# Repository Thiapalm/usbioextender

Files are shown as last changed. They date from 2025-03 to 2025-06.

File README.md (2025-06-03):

# USB to IO Extender Board

<p align=center>
 
 
</p>

This is a hobby development board conceived for usage in my home lab. The board can be used as USB to serial adapter with no need to install any driver on the PC. It can be used as USB to I2C adapter and also USB to GPIO port extender. For the two later options, some code development may be necessary.  

The board has 4 extra GPIO ports that can be used as LED indicators (if the back jumpers are soldered). The board power is provided by the USB connector, and it can be used in 5V or 3V3 modes for serial, I2C and GPIO pins. 

## License and certification

This is an open source hardware project licensed under CERN-OHL-P. More details on [LICENSE.md](./LICENSE.md).  

This project is certified by OSHW: [Certification BR000019](https://certification.oshwa.org/br000019.html)

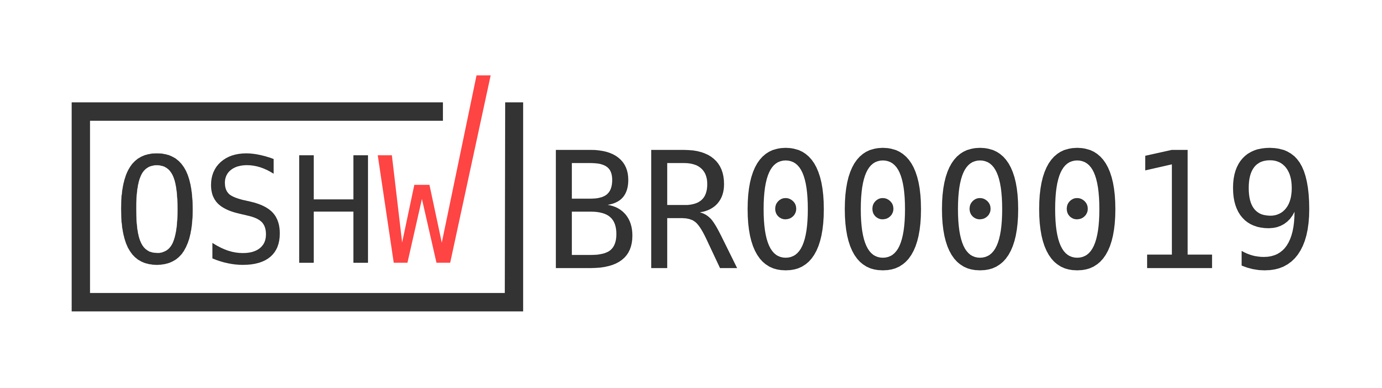
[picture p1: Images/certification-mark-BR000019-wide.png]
BR000019


## Project

The PCB project was developed in Kicad 9, all necessary project files are available in this repository and can be used freely, according to License.

## Board specifications

The board is based on the [**MCP2221**](https://www.microchip.com/en-us/product/MCP2221), and [**MCP23017**](https://www.microchip.com/en-us/product/MCP23017) from Microchip.  
Board features commonly used in Embedded Systems:
- USB-C connector
- I²C serial communication
- UART serial communication
- LED indicators (UART-TX, UART-RX, I²C, USB-Config and board power ON) or 4 extra GPIOs
- 16 GPIOs (5V or 3V3)
- Board power selector (5V / 3V3)
- The GPIO pins are breadboard compatible

## Board View 

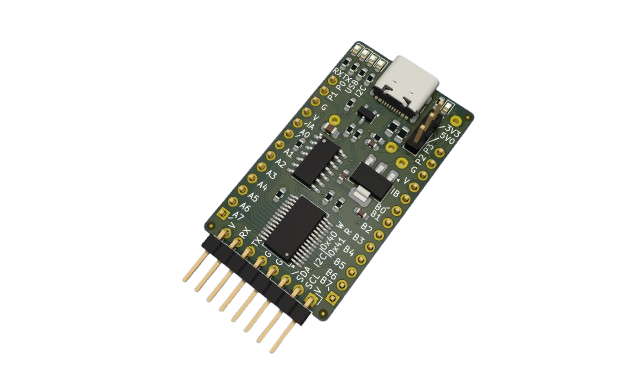
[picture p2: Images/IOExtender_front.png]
Front


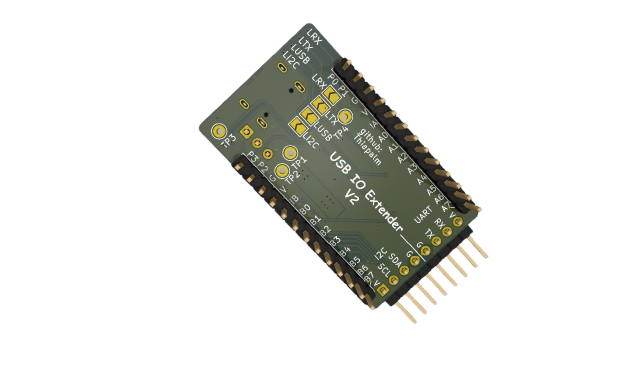
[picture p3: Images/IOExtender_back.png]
Back


## Version Revision

V1 - Not Published  
   - Added MCP23017 GPIOs on the header  
   - Added Jumper selector on LEDs  
   - Added Output voltage selection  
   - Added MCP2221 serial on Header  
   - Added MCP2221 I2C on Header   

V2 - Current Version
   - Changed USB connector to USB-C

## Firmware

There is no specific firmware for this board, but i have a driver developed in RUST for MCP23017 for use in embedded environments, see it in [crates.io](https://crates.io/crates/mcp23017-tp).

Also, you can use the IOExtender Control Center which is a software that can be used to control the I²C communication via Windows/Linux/Mac machines [iocc software](https://github.com/Thiapalm/iocc).

## Contribution

Unless you explicitly state otherwise, any contribution intentionally submitted for inclusion in the work by you, as defined in the CERN-OHL-P license, shall be licensed as above, without any additional terms or conditions.

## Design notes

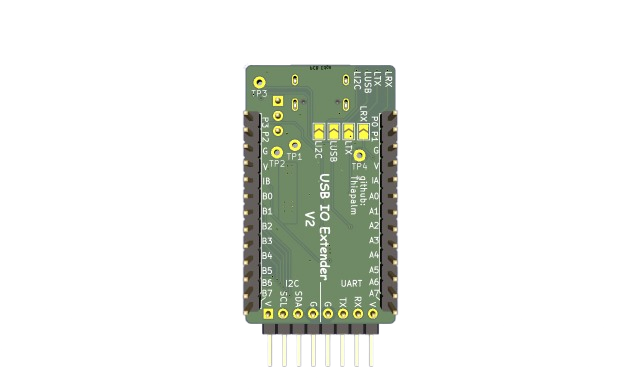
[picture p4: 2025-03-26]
Images/IOExtender_bottom.png

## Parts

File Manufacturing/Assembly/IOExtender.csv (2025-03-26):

Id | Designator | Footprint | Quantity | Designation | Supplier and ref
1 | U1 | SSOP-28_5.3x10.2mm_P0.65mm | 1 | MCP23017_SS
2 | R9,R3,R2,R10 | R_0603_1608Metric_Pad0.98x0.95mm_HandSolder | 4 | 10K
3 | R8,R7,R4,R5,R6 | R_0603_1608Metric_Pad0.98x0.95mm_HandSolder | 5 | 330
4 | R11,R1 | R_0603_1608Metric_Pad0.98x0.95mm_HandSolder | 2 | 33
5 | C2 | C_0603_1608Metric_Pad1.08x0.95mm_HandSolder | 1 | c=47e-7
6 | L1,L2 | R_0805_2012Metric_Pad1.20x1.40mm_HandSolder | 2 | 330R
7 | D6,D7 | LED_0603_1608Metric | 2 | Green
8 | D1,D5 | LED_0603_1608Metric | 2 | yellow
9 | C5 | USB_C_Receptacle_GCT_USB4105-xx-A_16P_TopMnt_Horizontal | 1 | USB4215-03-A
10 | J9 | PinHeader_1x08_P2.54mm_Horizontal | 1 | 22-28-8083
11 | J1 | PinHeader_1x03_P2.54mm_Vertical | 1 | 1x3 pin vertical
12 | D2 | LED_0603_1608Metric | 1 | Red
13 | U3 | SOT-223-3_TabPin2 | 1 | NCP1117IST33T3G
14 | U2 | SOIC-14_3.9x8.7mm_P1.27mm | 1 | MCP2221AxSL
15 | C6 | C_0603_1608Metric_Pad1.08x0.95mm_HandSolder | 1 | c=10e-6
16 | R12,R13 | R_0603_1608Metric_Pad0.98x0.95mm_HandSolder | 2 | 5.1K
17 | C8 | C_0805_2012Metric_Pad1.18x1.45mm_HandSolder | 1 | c=100e-9
18 | D4 | SOT-23-3 | 1 | CDSOT23-T05LC-Q
19 | C1 | C_0603_1608Metric_Pad1.08x0.95mm_HandSolder | 1 | c=470e-9
20 | J2,J5 | PinHeader_1x13_P2.54mm_Vertical | 2 | 1x13

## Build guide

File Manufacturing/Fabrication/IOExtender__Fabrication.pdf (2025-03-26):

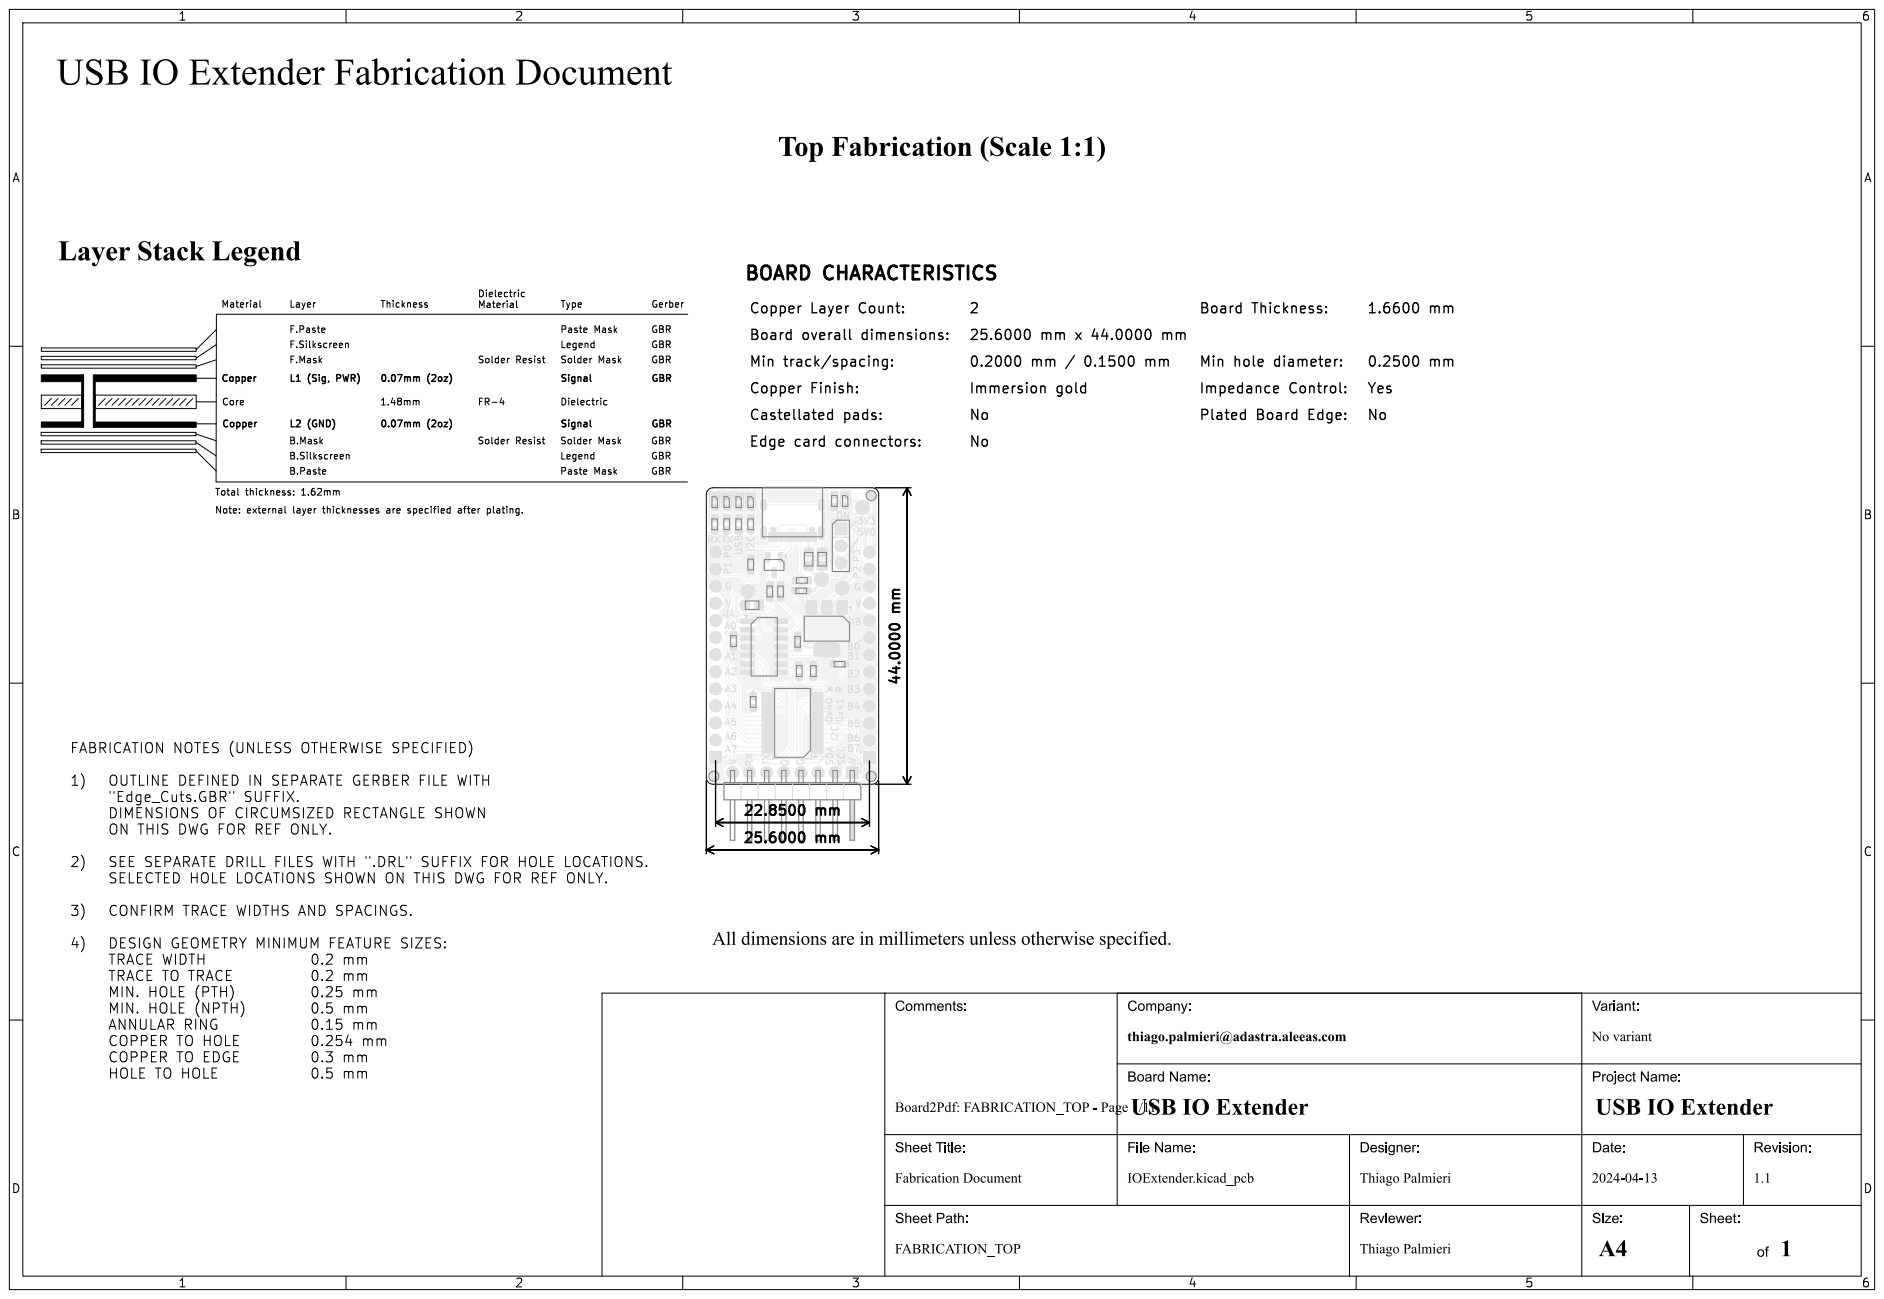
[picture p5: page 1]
USB G RX; SCL A6; SDA P¹; V Edge card; connectors: GBR GBR; Castellated; pads:; Total thickness:; Material; FR-4 Solder Resist; GBR; Legend; Copper; Layer Count:; No FABRICATION; NOTES (UNLESS OTHERWISE SPECIFIED); 1) OUTLINE; DEFINED IN; SEPARATE; GERBER; FILE; WITH; "Edge_Cuts.GBR"; SUFFIX. DIMENSIONS; OF CIRCUMSIZED; RECTANGLE SHOWN ON; THIS; DWG; FOR; REF ONLY. 2) SEE; DRILL; FILES; ".DRL"; SUFFIX; HOLE LOCATIONS. SELECTED; HOLE; LOCATIONS SHOWN ON; REF ONLY. 3) CONFIRM; TRACE; WIDTHS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

Sheet Path: FabricationDocument Comments: Board2Pdf:FABRICATION_TOP- Page1/11 USBIO ExtenderFabricationDocument

thiago.palmieri@adastra.aleeas.com

Revision: 1.1 Date: Project Name: 2024-04-13 Reviewer: ThiagoPalmieri Designer:

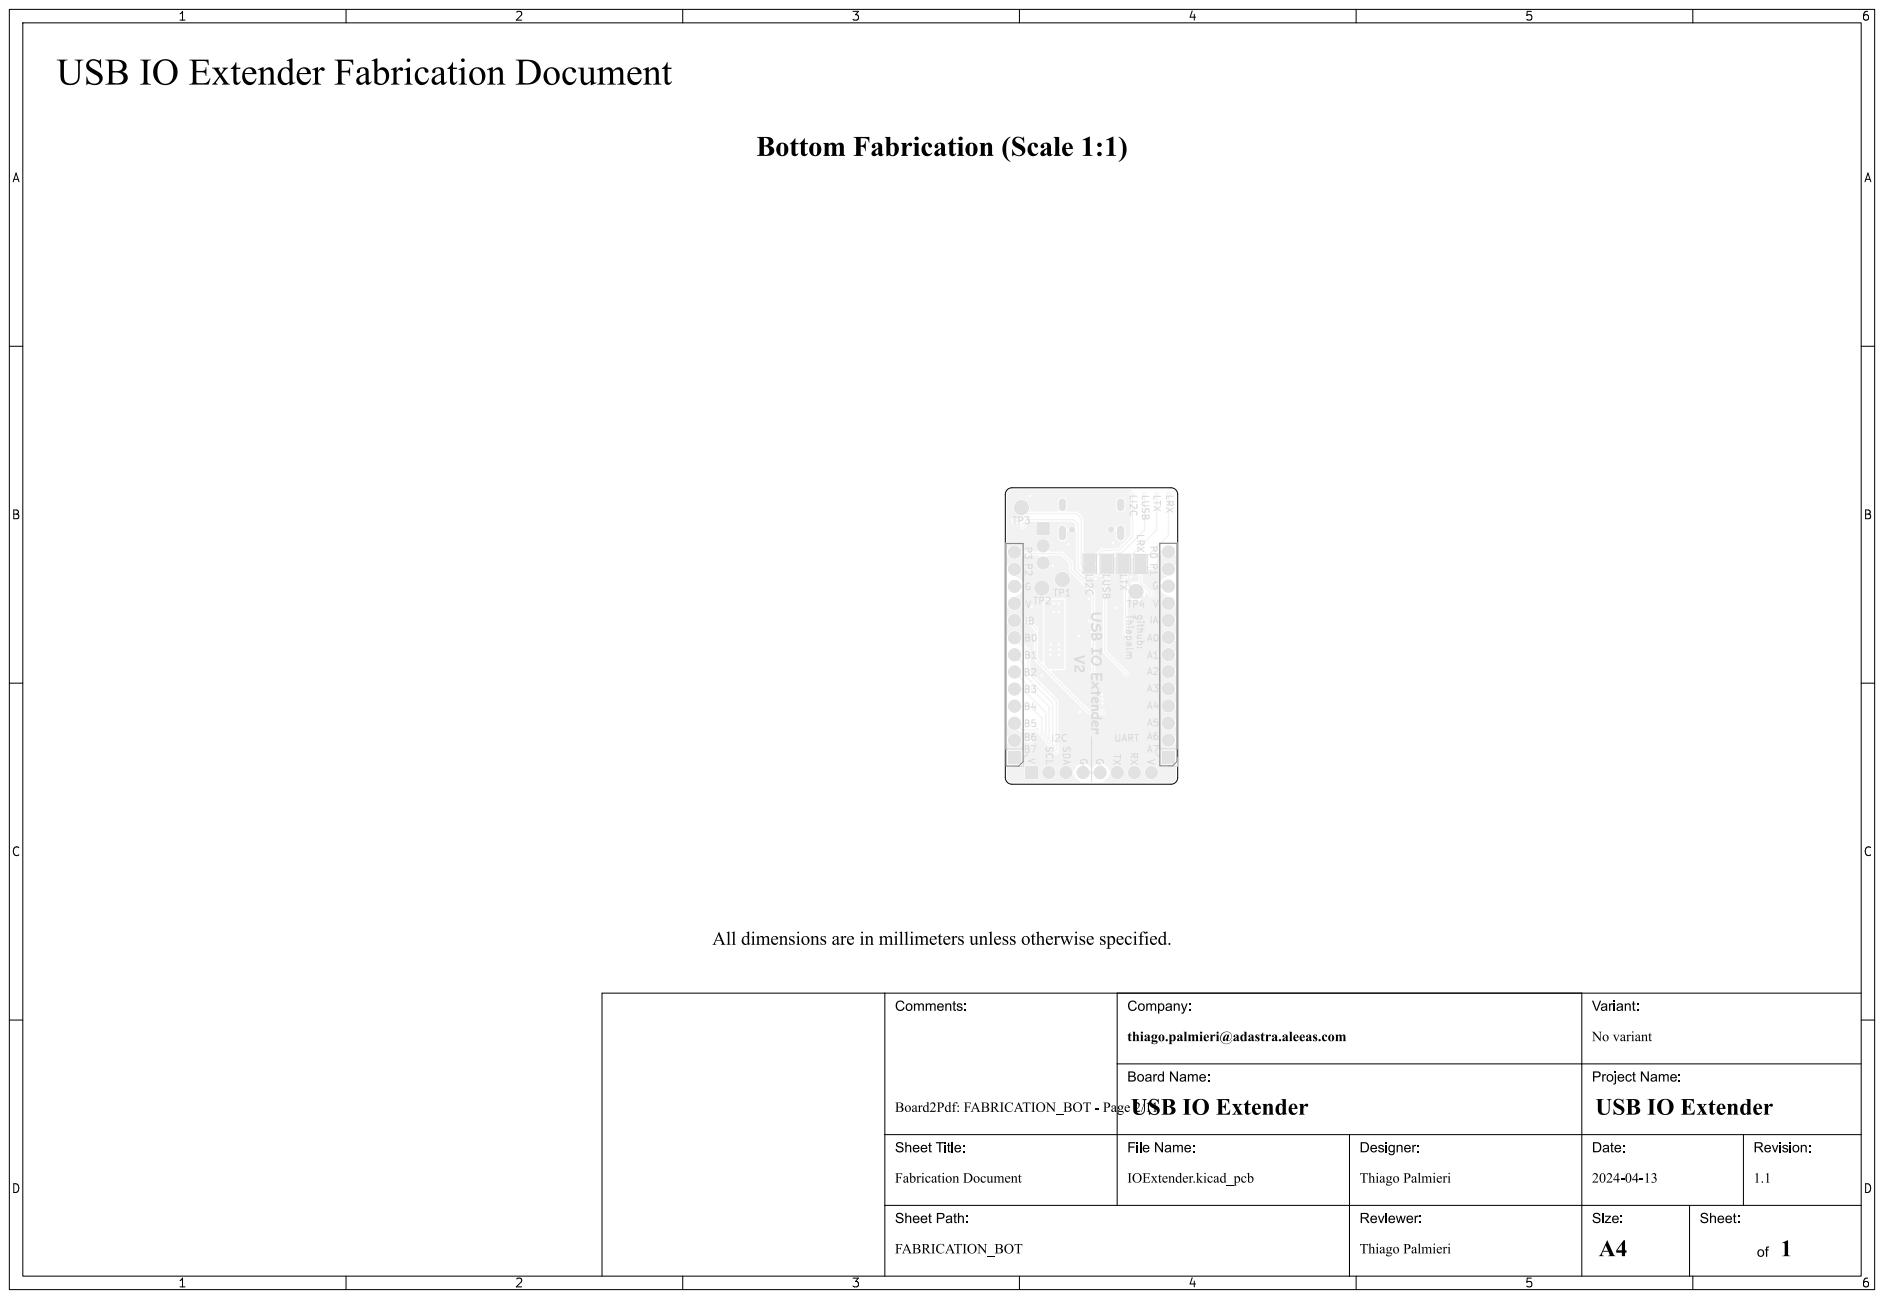
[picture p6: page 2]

thiago.palmieri@adastra.aleeas.com

Revision: 1.1 Date: Project Name: 2024-04-13 Reviewer: ThiagoPalmieri Designer:

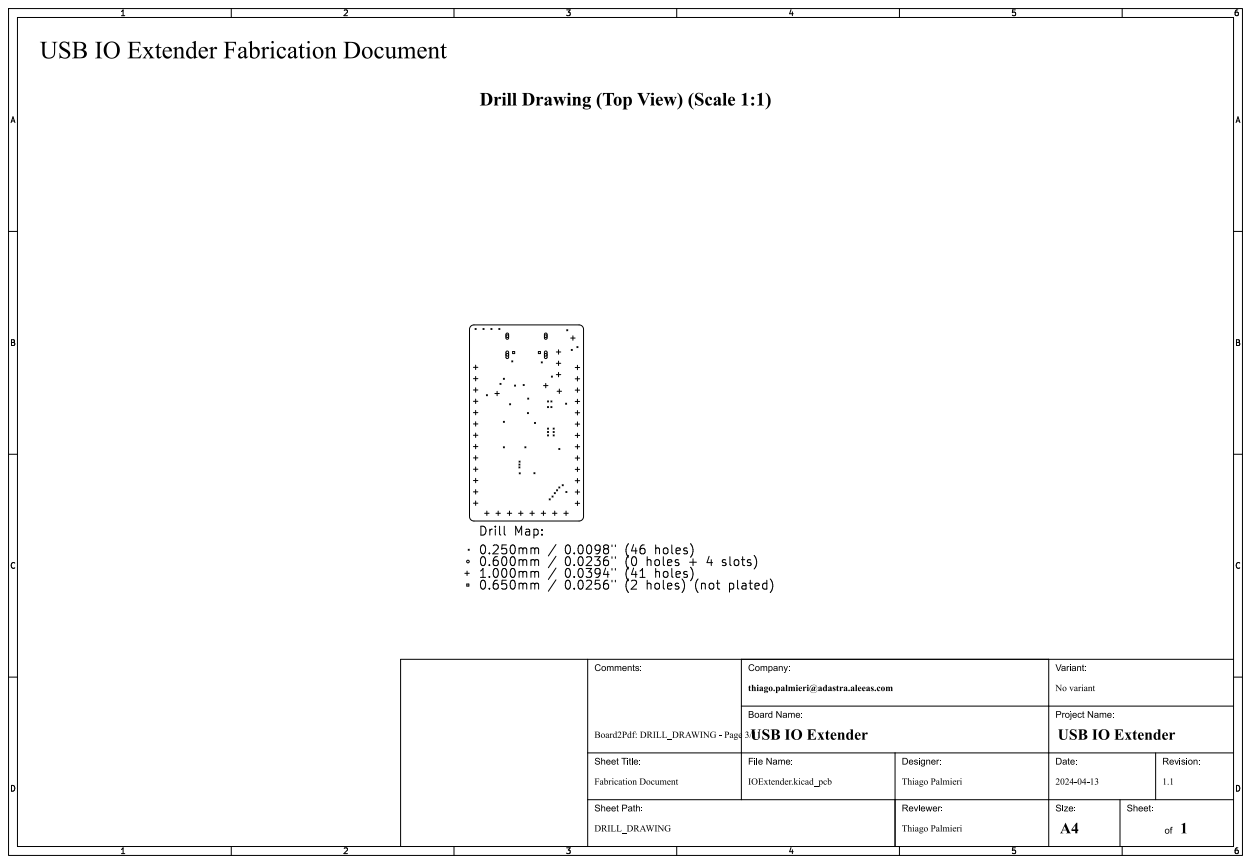
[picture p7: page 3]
D Sheet: of 1; Size: A4; IOExtender.kicad_pcb; ThiagoPalmieri Board Name:; Variant: No variant Company:; USBIO Extender; USBIO Extender Sheet Title:; File Name: DRILL_DRAWING

Sheet Path: FabricationDocument Comments: Board2Pdf:DRILL_DRAWING - Page3/11 USBIO ExtenderFabricationDocument

thiago.palmieri@adastra.aleeas.com

Revision: 1.1 Date: Project Name: 2024-04-13 Reviewer: ThiagoPalmieri Designer:

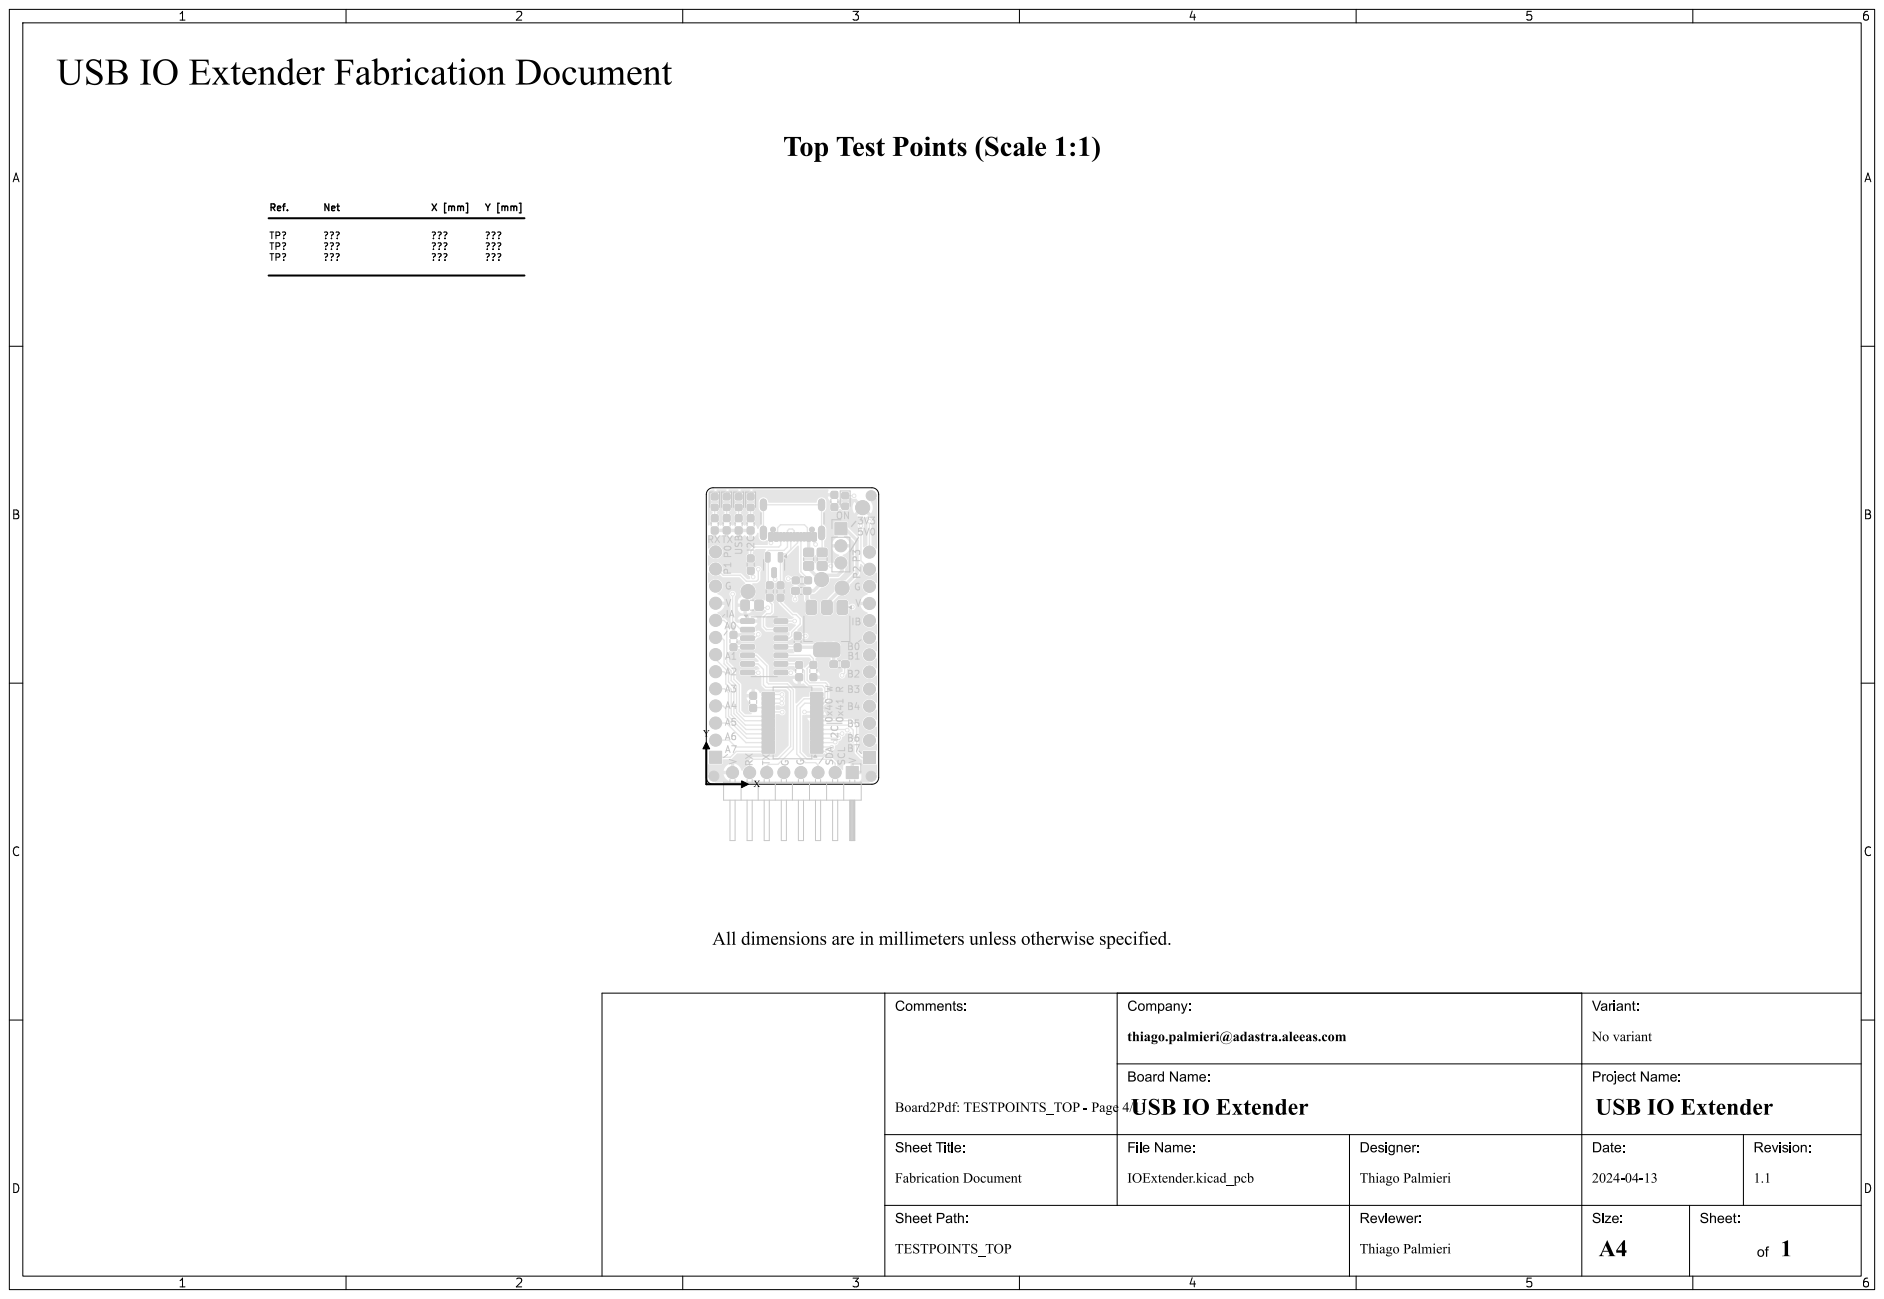
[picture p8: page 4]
USB G RX; SCL A6; SDA P¹; ??? Ref.; ??? Net; D Sheet: of 1; Size: A4; IOExtender.kicad_pcb; ThiagoPalmieri Board Name:; Variant: No variant Company:; USBIO Extender; USBIO Extender Sheet Title:; File Name: TESTPOINTS_TOP

Sheet Path: FabricationDocument Comments: Board2Pdf:TESTPOINTS_TOP- Page4/11 USBIO ExtenderFabricationDocument

thiago.palmieri@adastra.aleeas.com

Revision: 1.1 Date: Project Name: 2024-04-13 Reviewer: ThiagoPalmieri Designer:

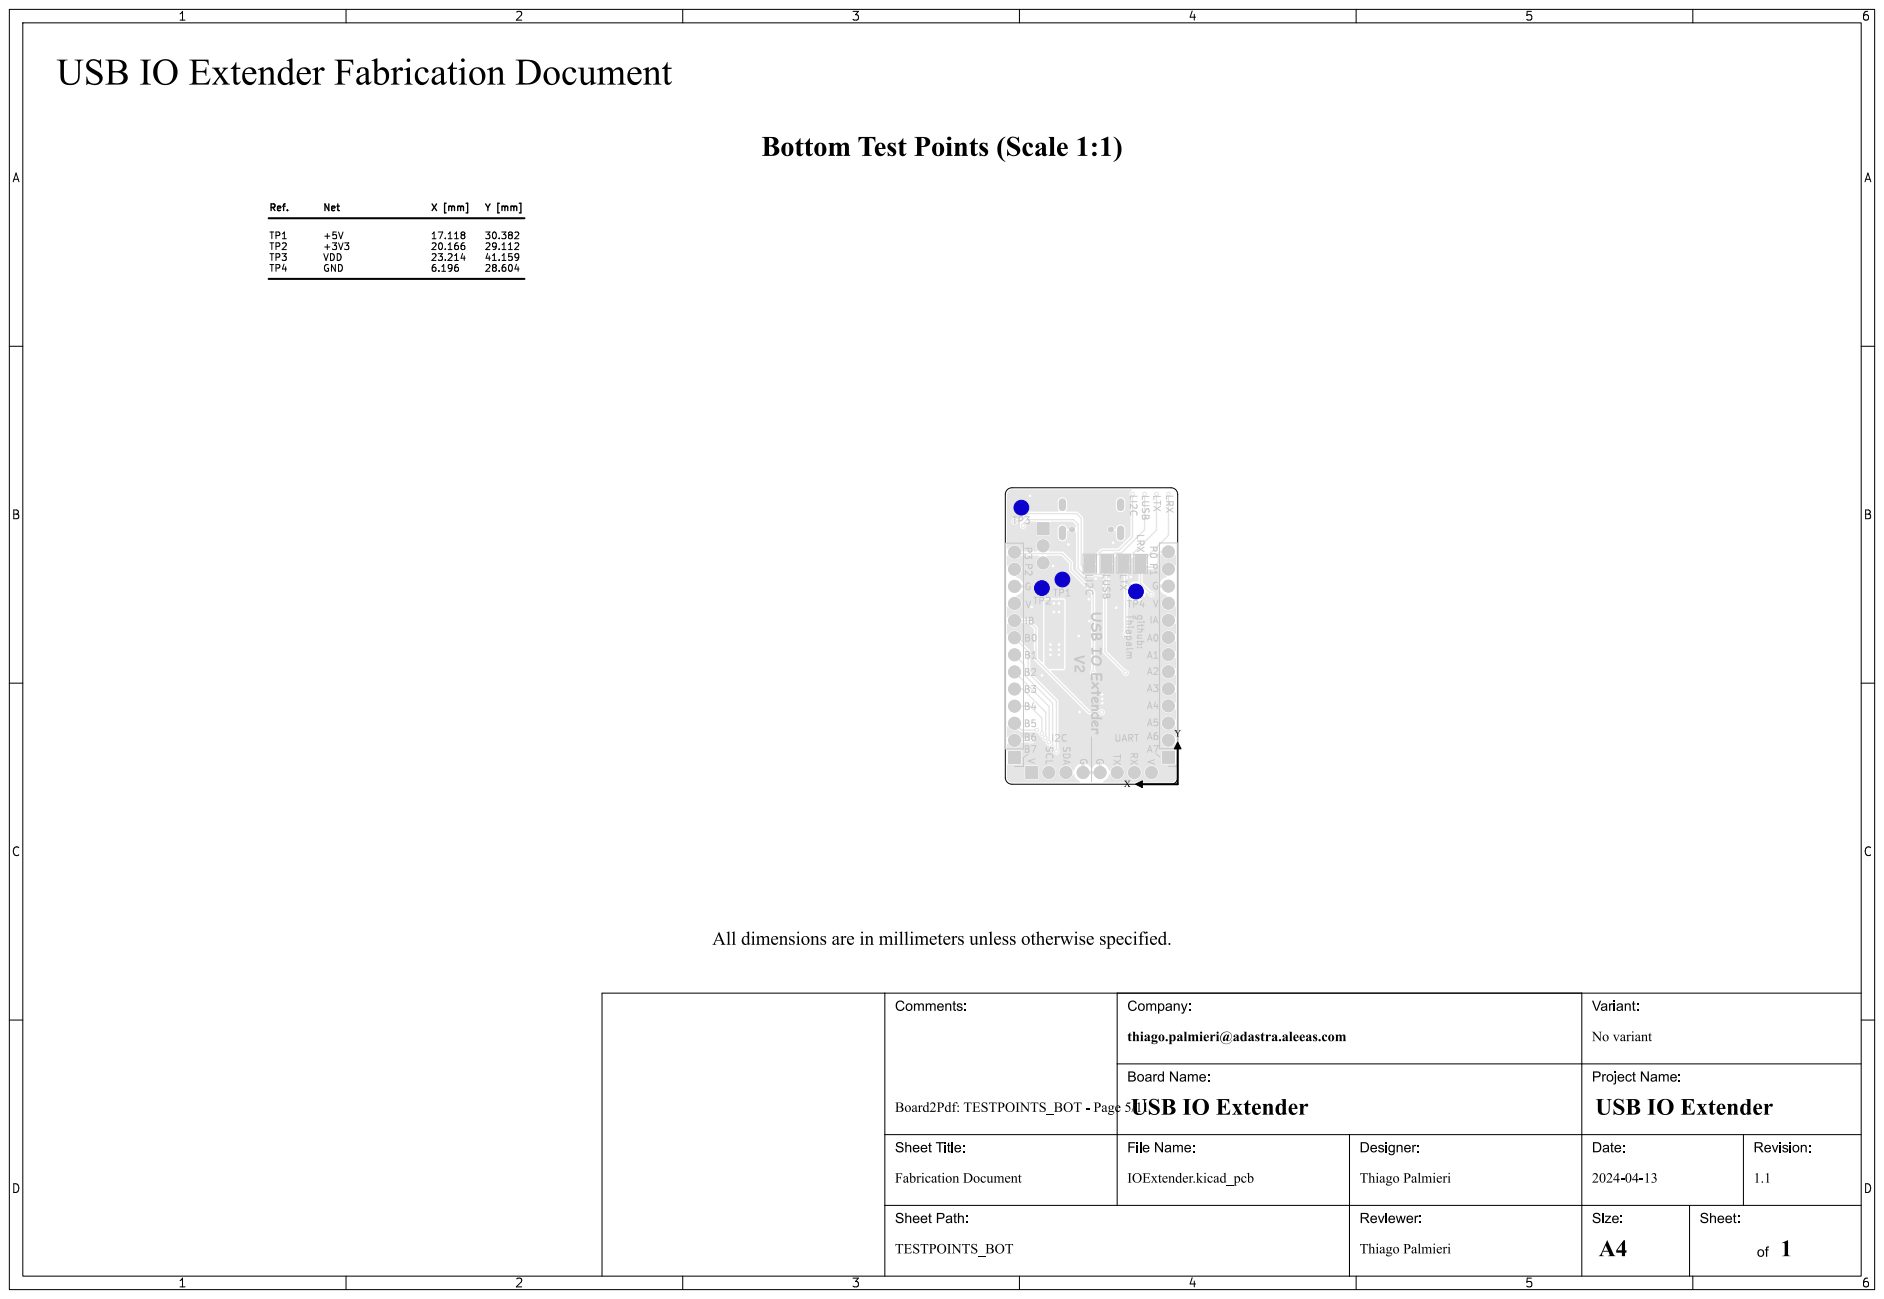
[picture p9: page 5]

thiago.palmieri@adastra.aleeas.com

Revision: 1.1 Date: Project Name: 2024-04-13 Reviewer: ThiagoPalmieri Designer:

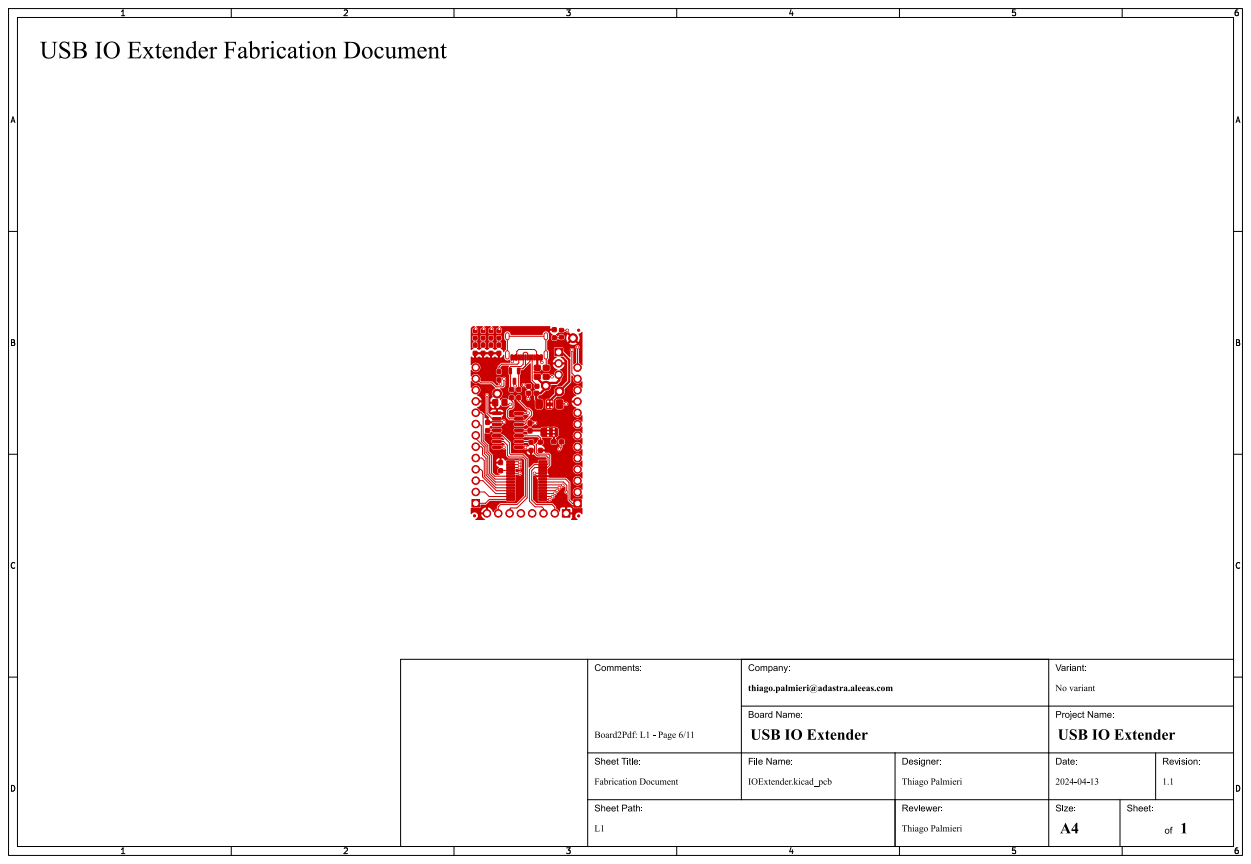
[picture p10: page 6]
D Sheet: of 1; Size: A4; IOExtender.kicad_pcb; ThiagoPalmieri Board Name:; Variant: No variant Company:; USBIO Extender; USBIO Extender Sheet Title:; File Name: L1Sheet Path: FabricationDocument Comments: Board2Pdf:L1 - Page6/11 USBIO ExtenderFabricationDocument

thiago.palmieri@adastra.aleeas.com

Revision: 1.1 Date: Project Name: 2024-04-13 Reviewer: ThiagoPalmieri Designer:

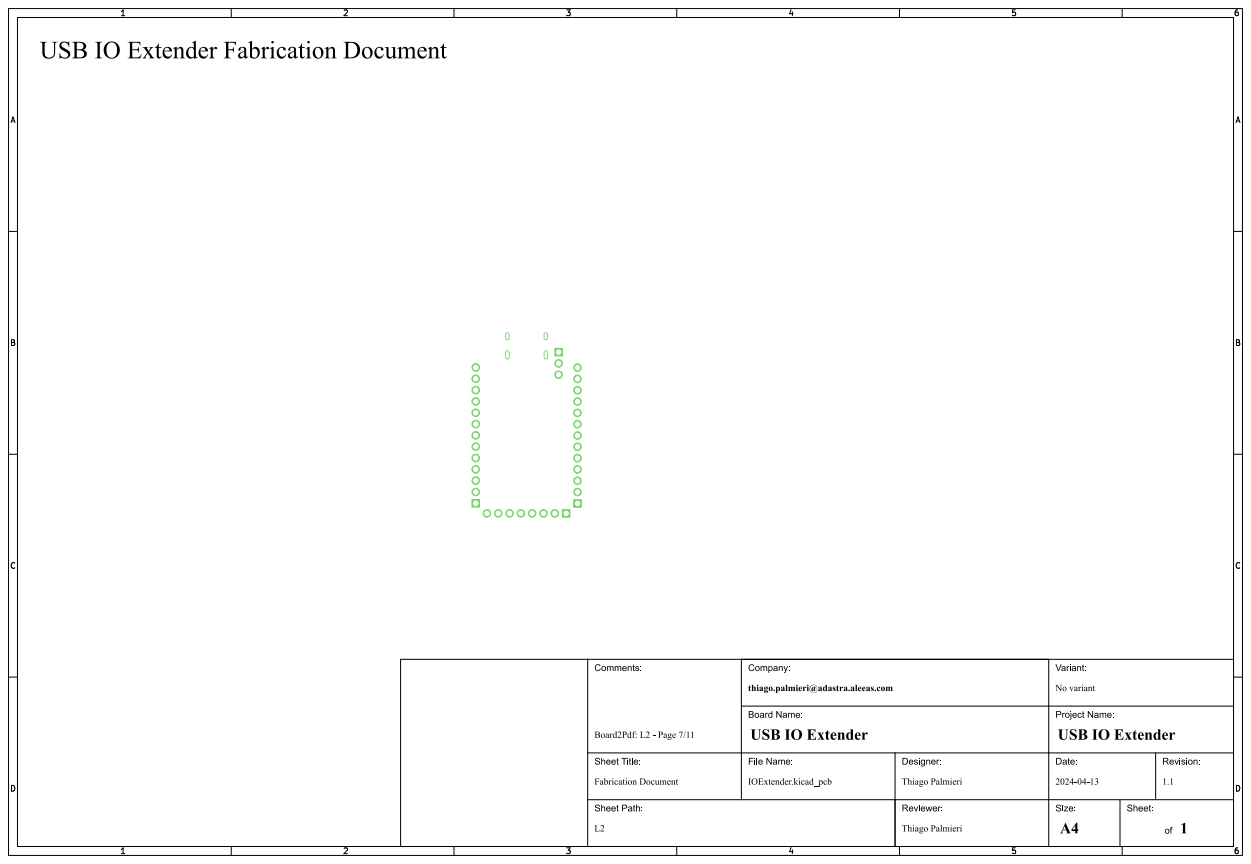
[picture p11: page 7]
D Sheet: of 1; Size: A4; IOExtender.kicad_pcb; ThiagoPalmieri Board Name:; Variant: No variant Company:; USBIO Extender; USBIO Extender Sheet Title:; File Name: L2Sheet Path: FabricationDocument Comments: Board2Pdf:L2 - Page7/11 USBIO ExtenderFabricationDocument

thiago.palmieri@adastra.aleeas.com

Revision: 1.1 Date: Project Name: 2024-04-13 Reviewer: ThiagoPalmieri Designer:

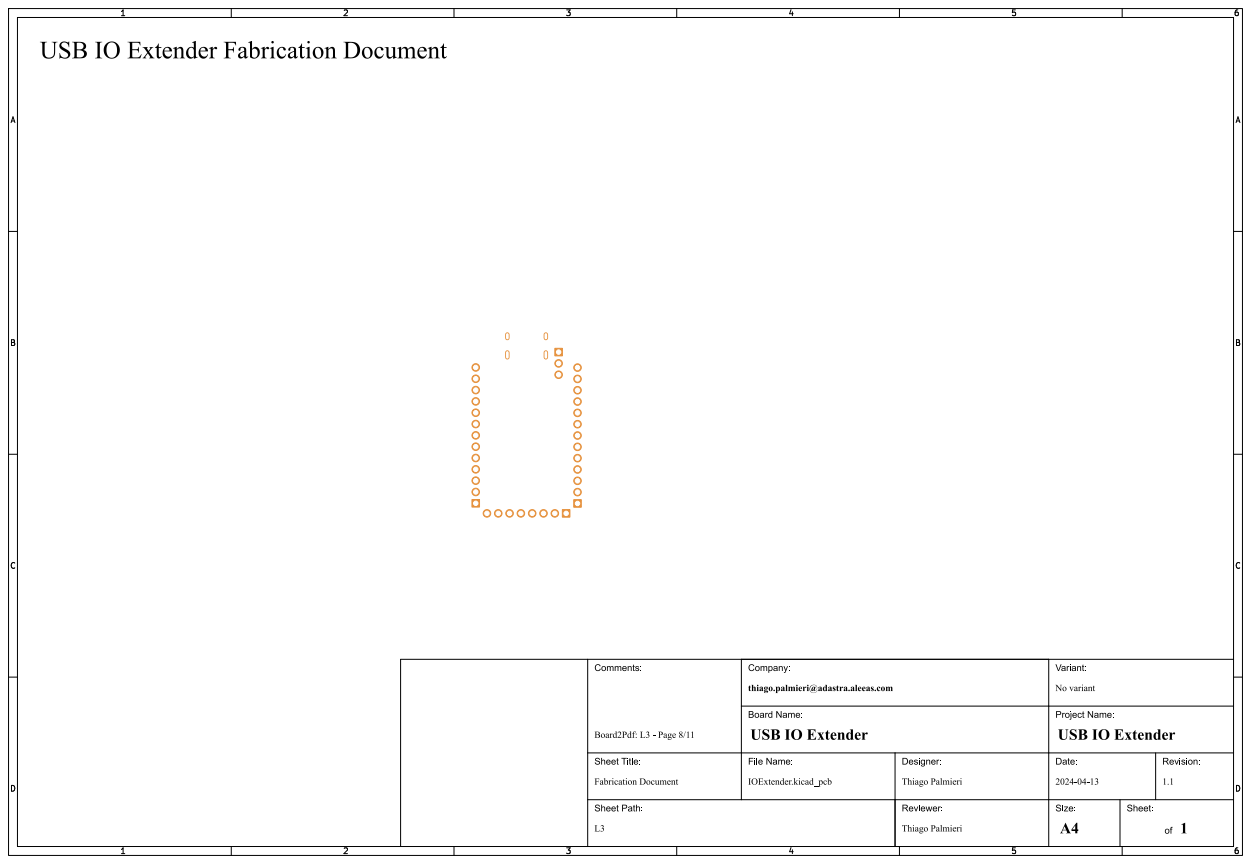
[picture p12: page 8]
D Sheet: of 1; Size: A4; IOExtender.kicad_pcb; ThiagoPalmieri Board Name:; Variant: No variant Company:; USBIO Extender; USBIO Extender Sheet Title:; File Name: L3Sheet Path: FabricationDocument Comments: Board2Pdf:L3 - Page8/11 USBIO ExtenderFabricationDocument

thiago.palmieri@adastra.aleeas.com

Revision: 1.1 Date: Project Name: 2024-04-13 Reviewer: ThiagoPalmieri Designer:

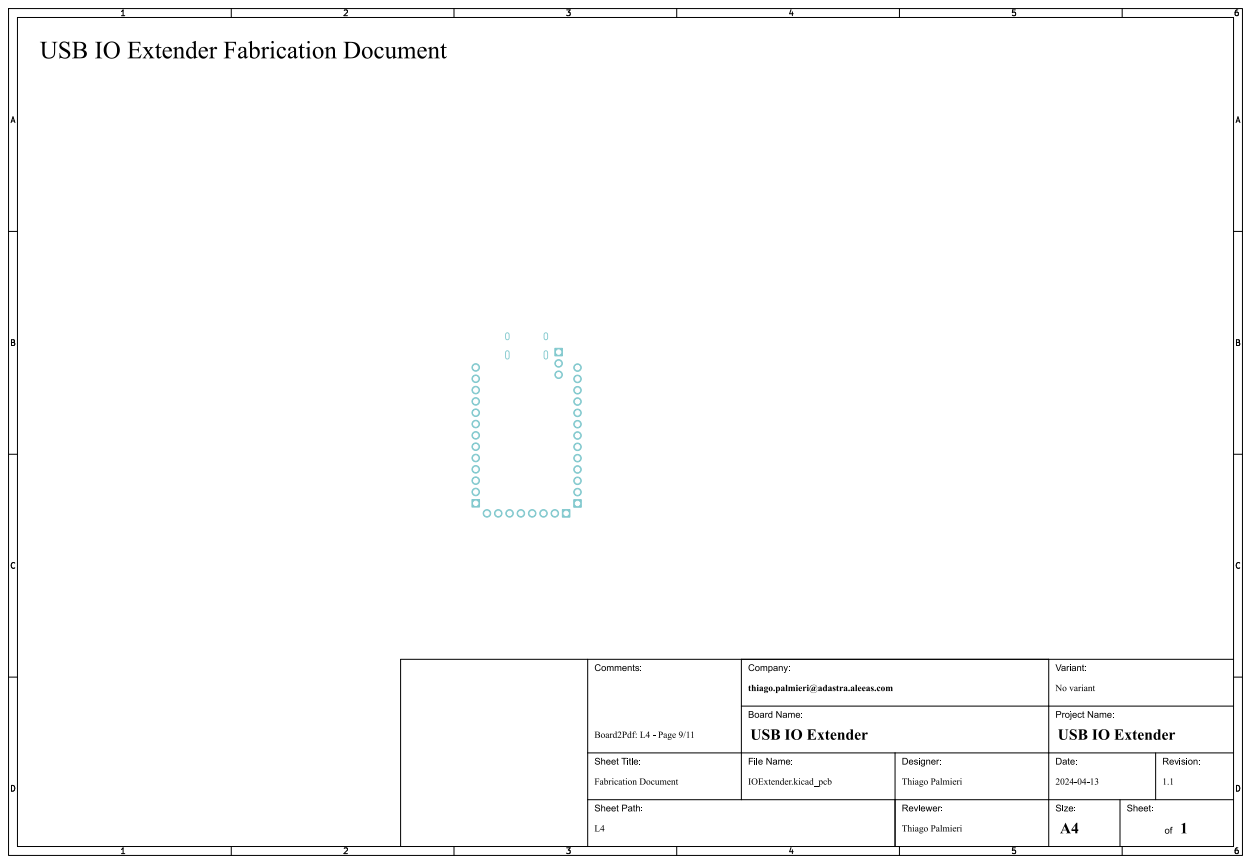
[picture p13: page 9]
D Sheet: of 1; Size: A4; IOExtender.kicad_pcb; ThiagoPalmieri Board Name:; Variant: No variant Company:; USBIO Extender; USBIO Extender Sheet Title:; File Name: L4Sheet Path: FabricationDocument Comments: Board2Pdf:L4 - Page9/11 USBIO ExtenderFabricationDocument

thiago.palmieri@adastra.aleeas.com

Revision: 1.1 Date: Project Name: 2024-04-13 Reviewer: ThiagoPalmieri Designer:

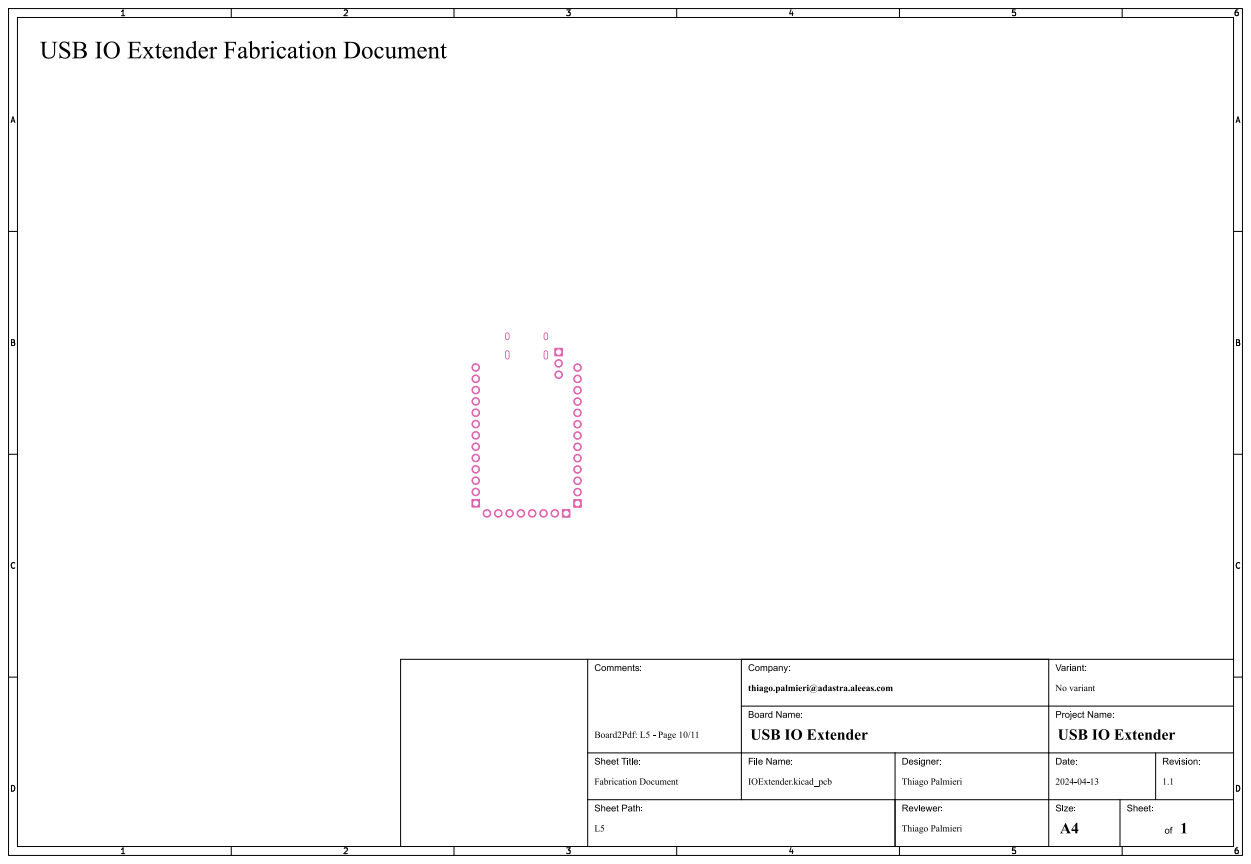
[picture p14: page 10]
D Sheet: of 1; Size: A4; IOExtender.kicad_pcb; ThiagoPalmieri Board Name:; Variant: No variant Company:; USBIO Extender; USBIO Extender Sheet Title:; File Name: L5Sheet Path: FabricationDocument Comments: Board2Pdf:L5 - Page10/11 USBIO ExtenderFabricationDocument

thiago.palmieri@adastra.aleeas.com

Revision: 1.1 Date: Project Name: 2024-04-13 Reviewer: ThiagoPalmieri Designer:

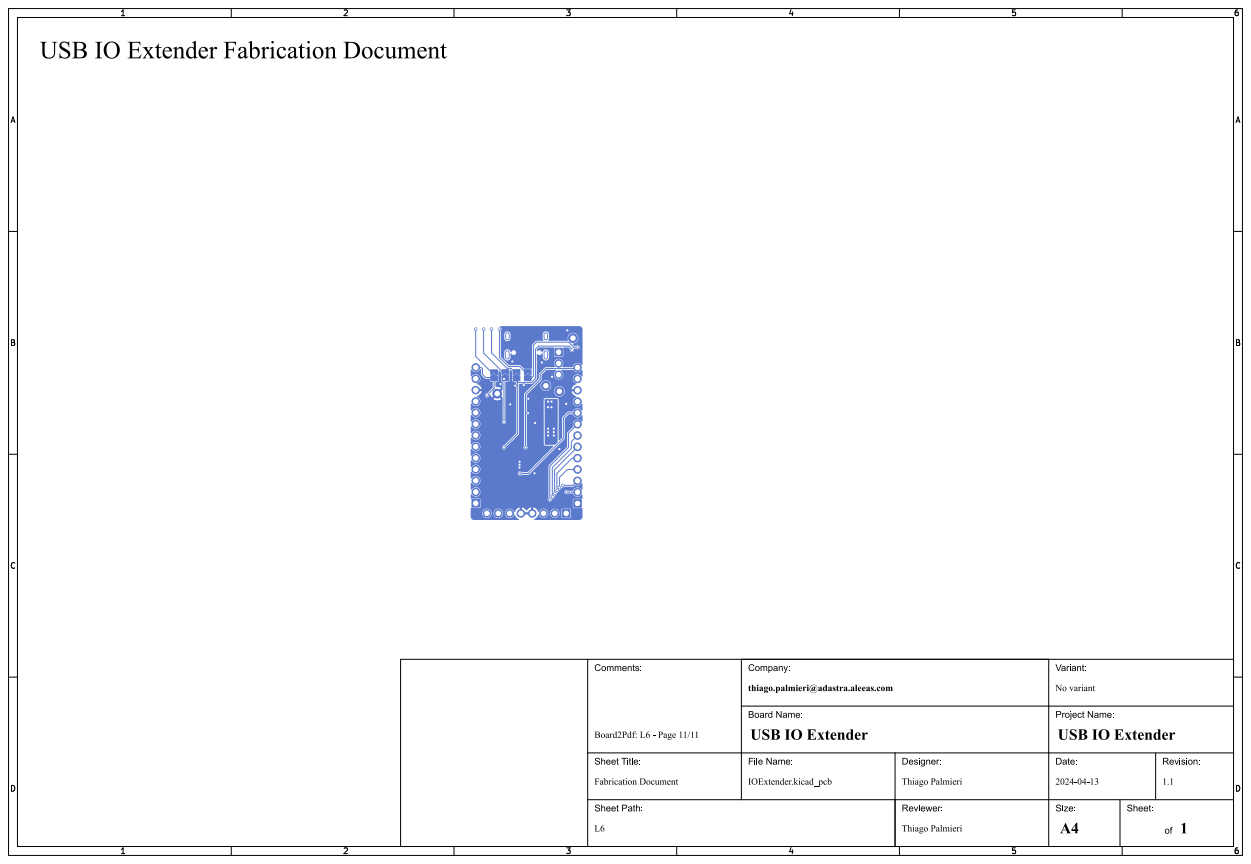
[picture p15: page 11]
D Sheet: of 1; Size: A4; IOExtender.kicad_pcb; ThiagoPalmieri Board Name:; Variant: No variant Company:; USBIO Extender; USBIO Extender Sheet Title:; File Name: L6Sheet Path: FabricationDocument Comments: Board2Pdf:L6 - Page11/11 USBIO ExtenderFabricationDocument

thiago.palmieri@adastra.aleeas.com

Revision: 1.1 Date: Project Name: 2024-04-13 Reviewer: ThiagoPalmieri Designer:

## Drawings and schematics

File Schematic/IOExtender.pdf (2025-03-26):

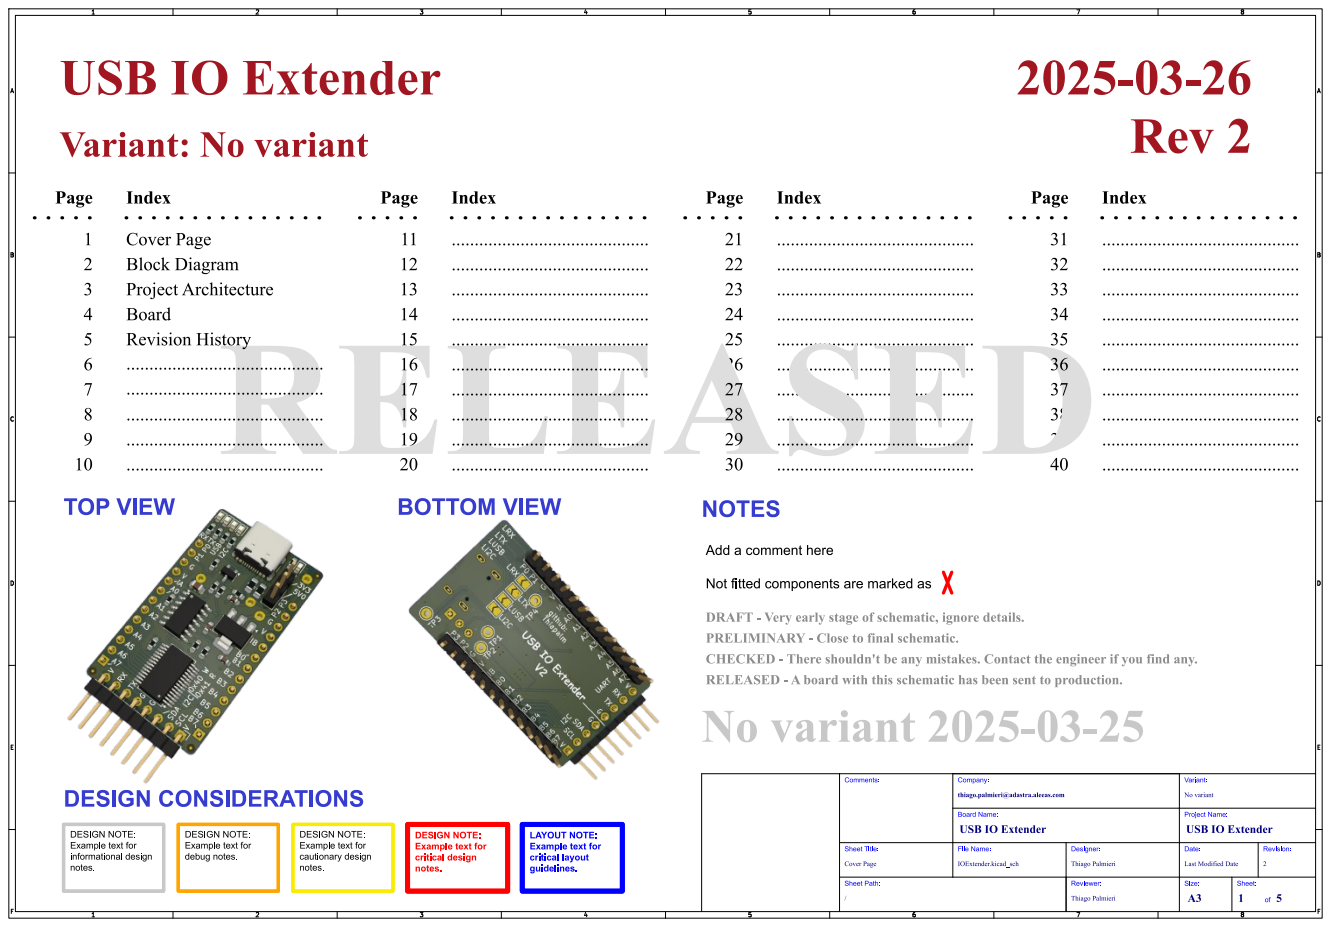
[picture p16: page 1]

........................................... DRAFT - Veryearlystageof schematic,ignoredetails.

........................................... Not fitted components are marked as

PRELIMINARY - Closetofinal schematic.
CHECKED - Thereshouldn'tbeanymistakes.Contacttheengineerif youfindany.
RELEASED - A boardwiththisschematichasbeensenttoproduction.
Novariant2025-03-25

thiago.palmieri@adastra.aleeas.com

Revision: 2 Date: Project Name: LastModified Date Reviewer: ThiagoPalmieri Designer:

File: Project Architecture.kicad_sch DESIGN NOTE:
Example text for
informational design
notes.

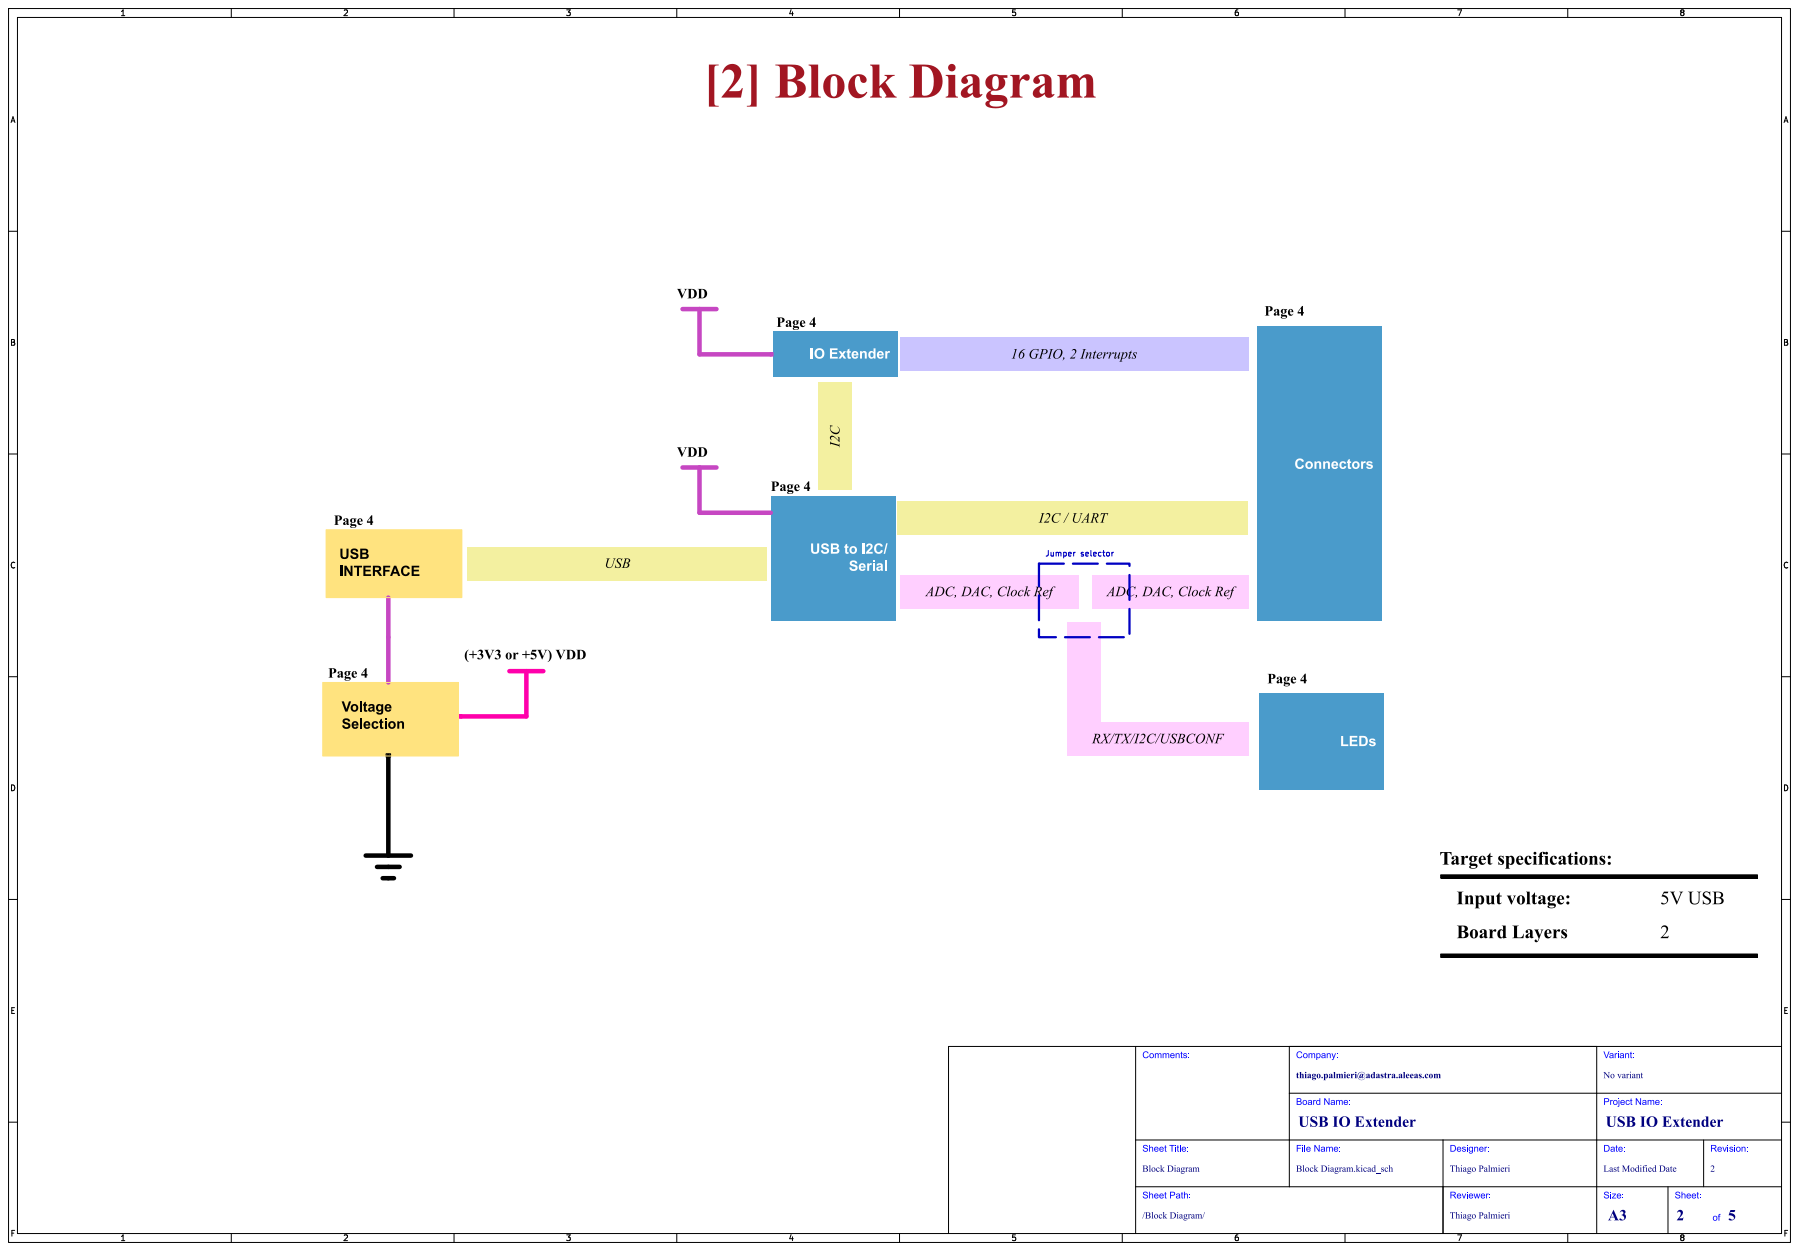
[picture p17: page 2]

Voltage

RX/TX/I2C/USBCONF

thiago.palmieri@adastra.aleeas.com

/Block Diagram/ Sheet Path: Block Diagram

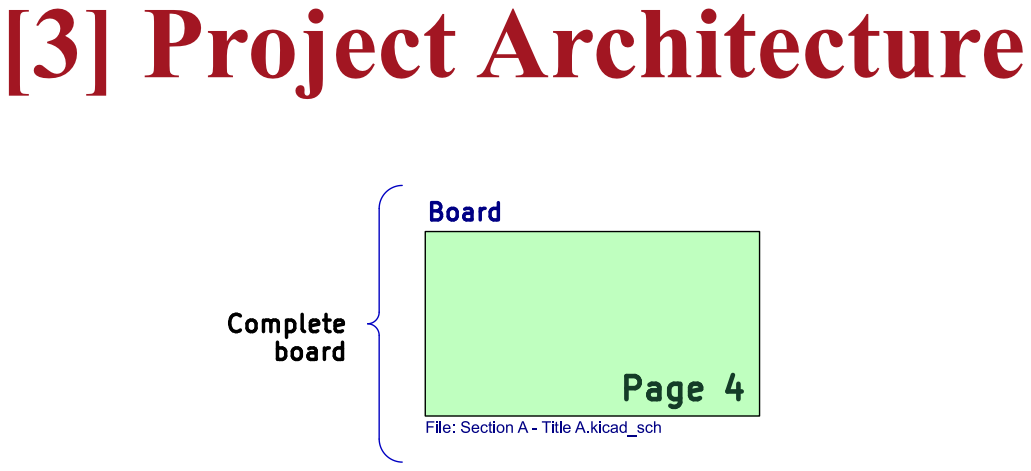
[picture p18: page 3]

File: Section A - Title A.kicad_sch [3] ProjectArchitecture

/ProjectArchitecture/ Sheet Path: ProjectArchitecture Comments:

thiago.palmieri@adastra.aleeas.com

Revision: 2 Date: Project Name: LastModified Date Reviewer: ThiagoPalmieri Designer:

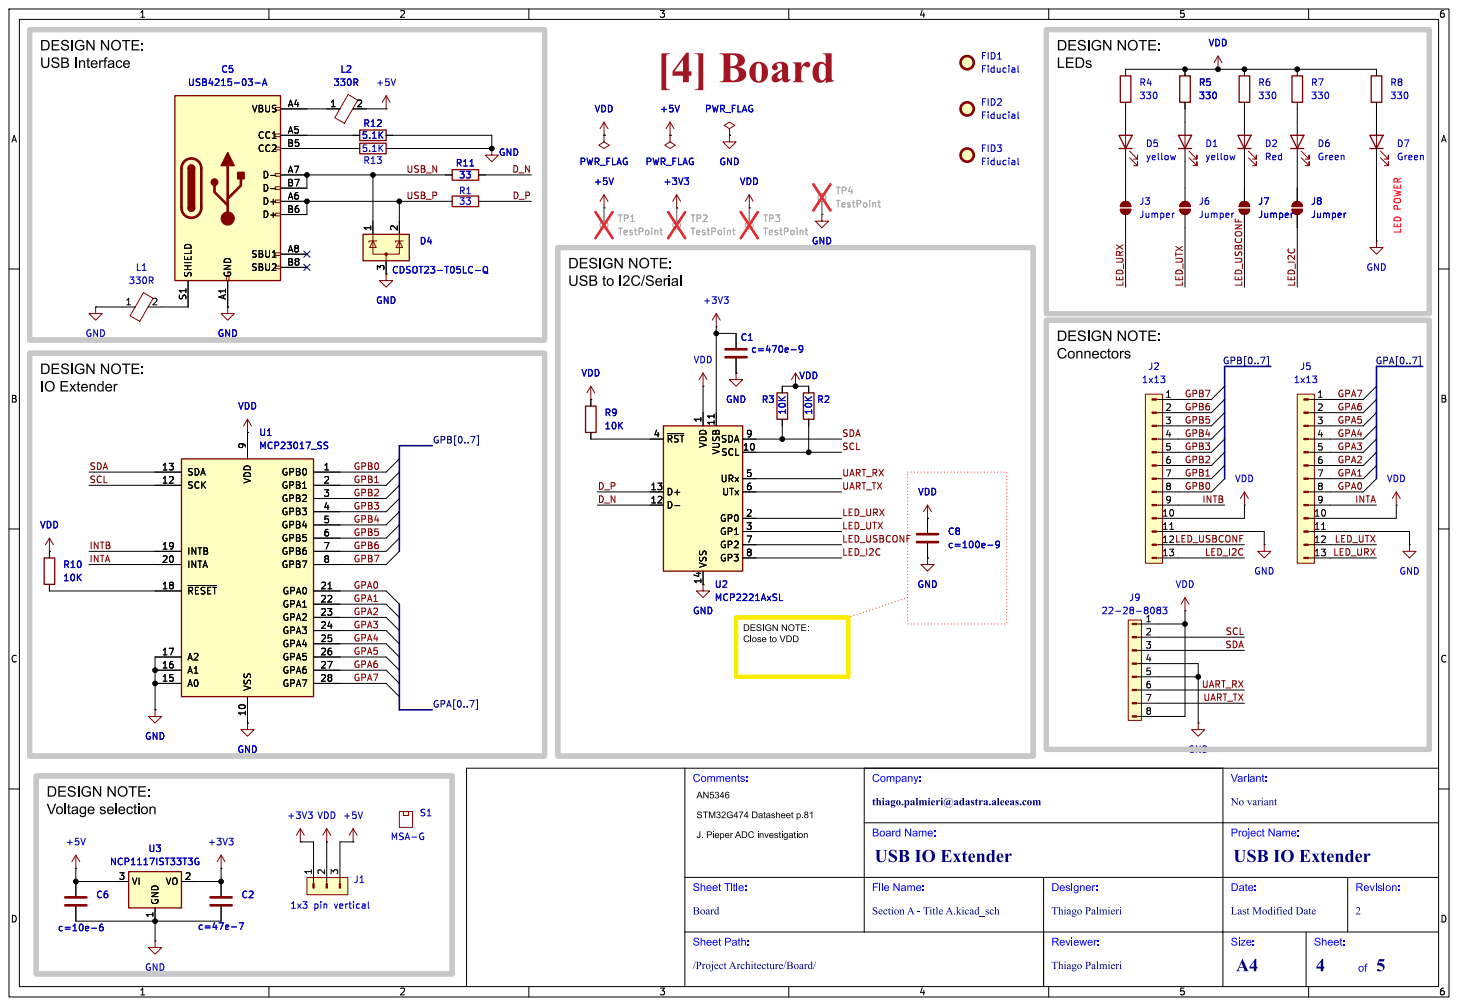
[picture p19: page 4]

1 VSS 14 VUSB 11 SDA 9 SCL 10 URx 5 UTx 6 GP0 2 GP1 3 GP2 7 GP3 8 GND GND GND

1 VSS 14 VUSB 11 SDA 9 SCL 10 URx 5 UTx 6 GP0 2 GP1 3 GP2 7 GP3 8 U2 MCP2221AxSL

thiago.palmieri@adastra.aleeas.com

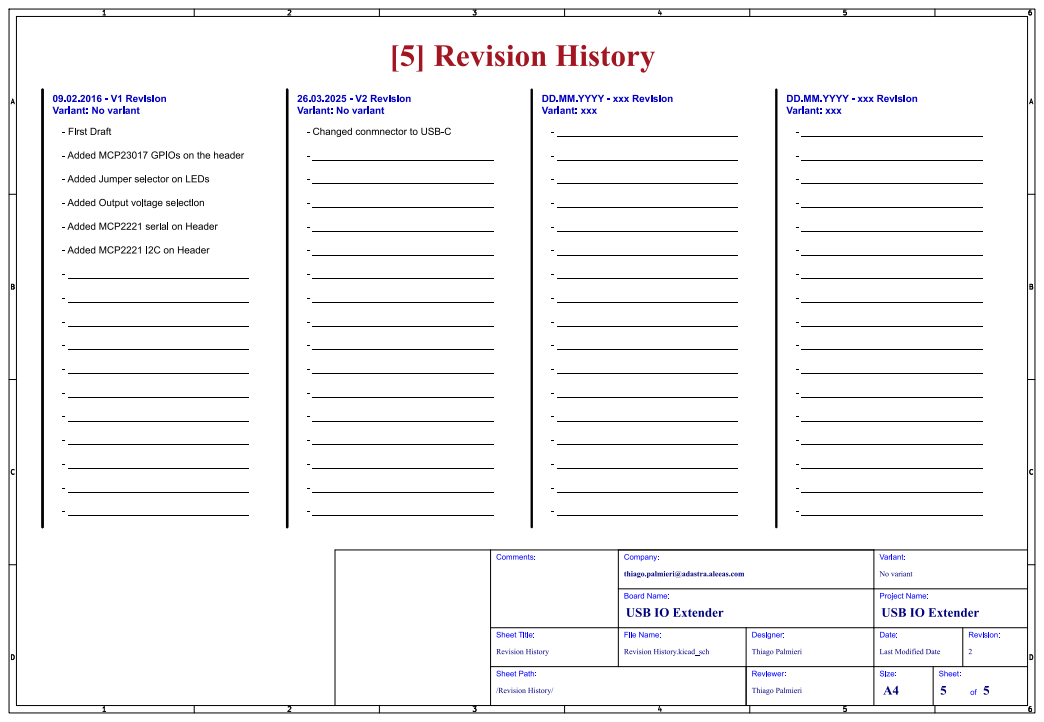
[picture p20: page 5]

09.02.2016 - V1 Revision
Variant: No variant
- First Draft - Added MCP23017 GPIOs on the header

26.03.2025 - V2 Revision
- Changed conmnector to USB-C

DD.MM.YYYY - xxx Revision
Variant: xxx

- Added Jumper selector on LEDs

- Added Output voltage selection

- Added MCP2221 serial on Header

/RevisionHistory/ Sheet Path: RevisionHistory Comments:

thiago.palmieri@adastra.aleeas.com

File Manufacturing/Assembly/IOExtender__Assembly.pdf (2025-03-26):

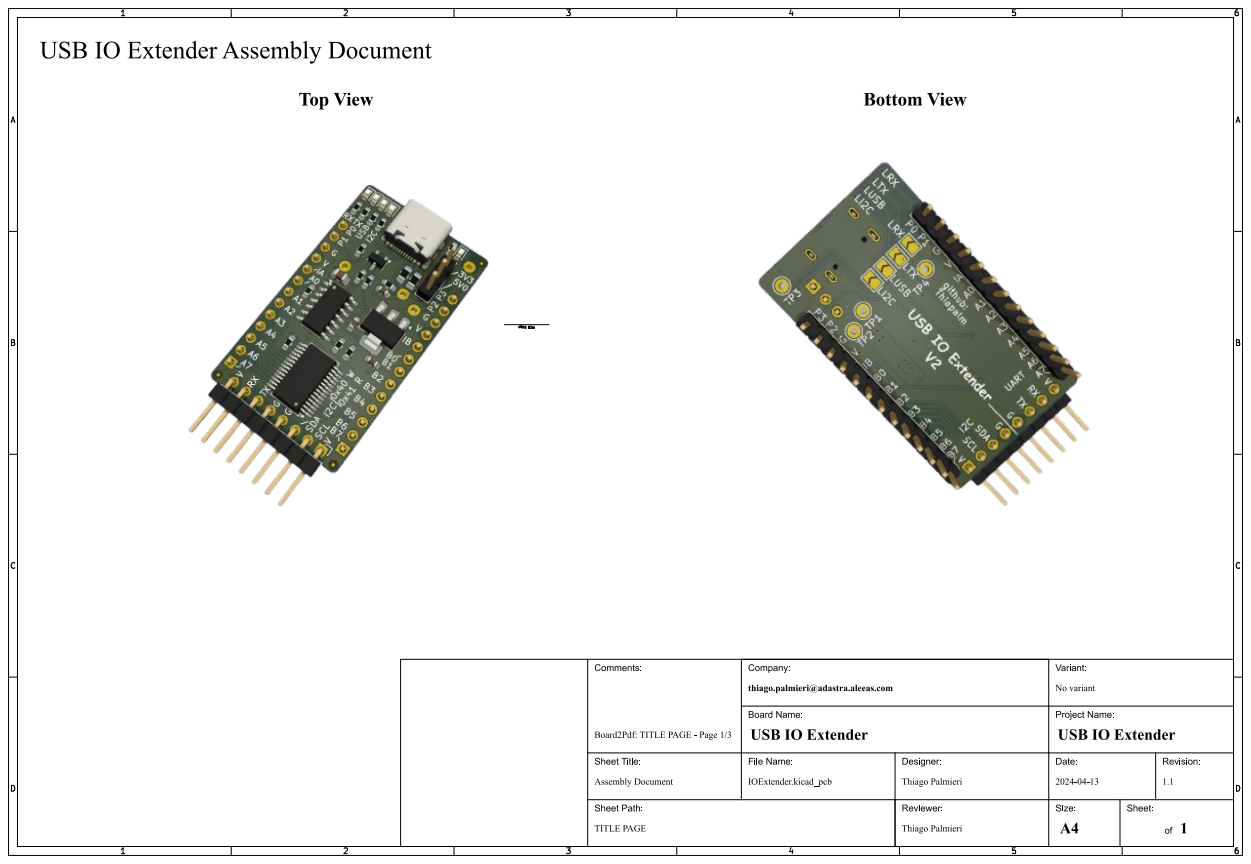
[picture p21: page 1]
D Sheet: of 1; Size: A4; IOExtender.kicad_pcb; ThiagoPalmieri Board Name:; Variant: No variant Company:; USBIO Extender; USBIO Extender Sheet Title:; File Name: TITLE PAGE

Sheet Path: AssemblyDocument Comments: Board2Pdf:TITLE PAGE- Page1/3 USBIO ExtenderAssemblyDocument

thiago.palmieri@adastra.aleeas.com

Revision: 1.1 Date: Project Name: 2024-04-13 Reviewer: ThiagoPalmieri Designer:

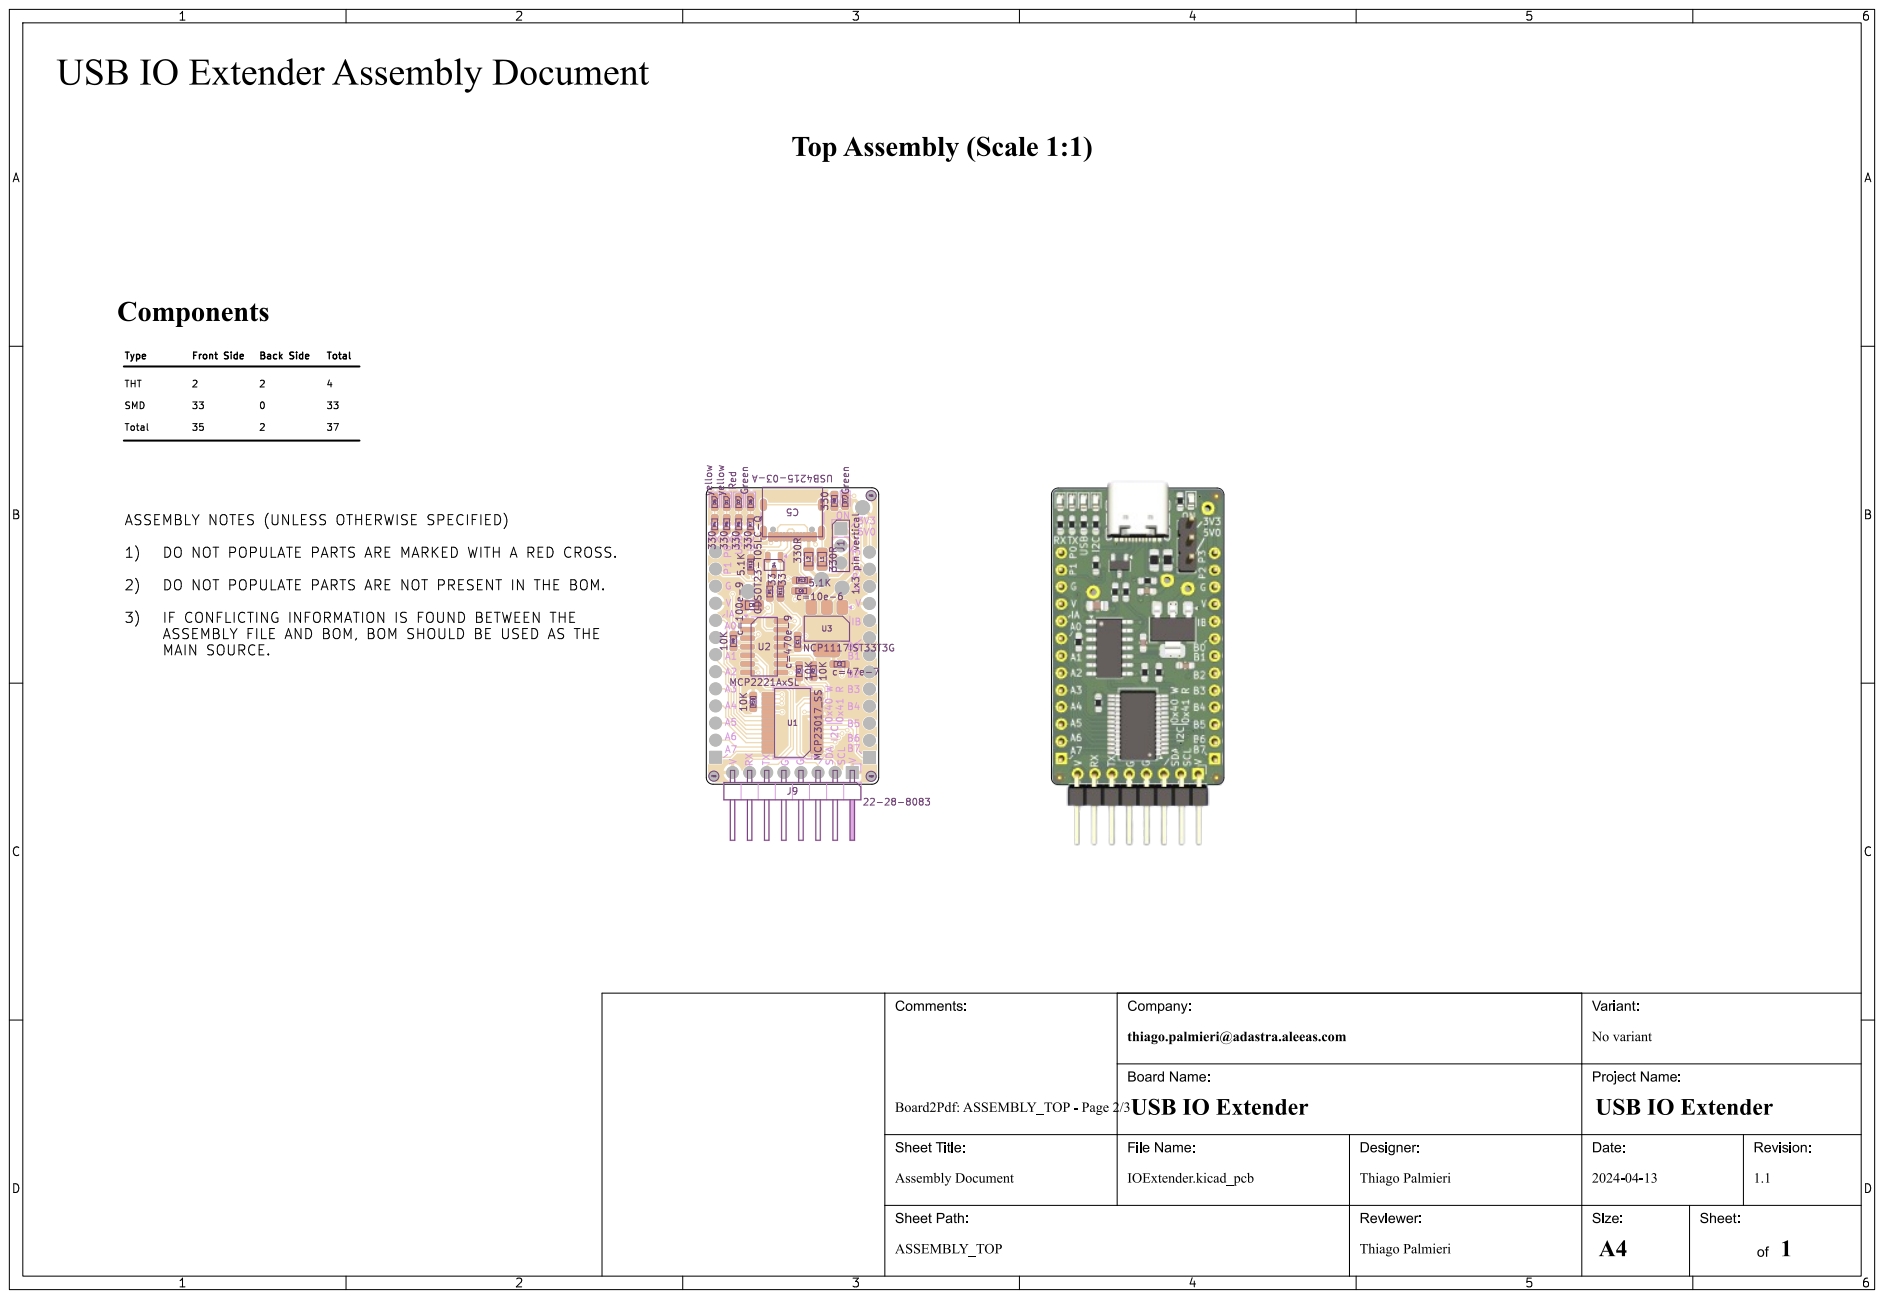
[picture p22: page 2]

Sheet Path: AssemblyDocument Comments: Board2Pdf:ASSEMBLY_TOP- Page2/3 USBIO ExtenderAssemblyDocument

37 ASSEMBLY NOTES (UNLESS OTHERWISE SPECIFIED)

thiago.palmieri@adastra.aleeas.com

Revision: 1.1 Date: Project Name: 2024-04-13 Reviewer: ThiagoPalmieri Designer:

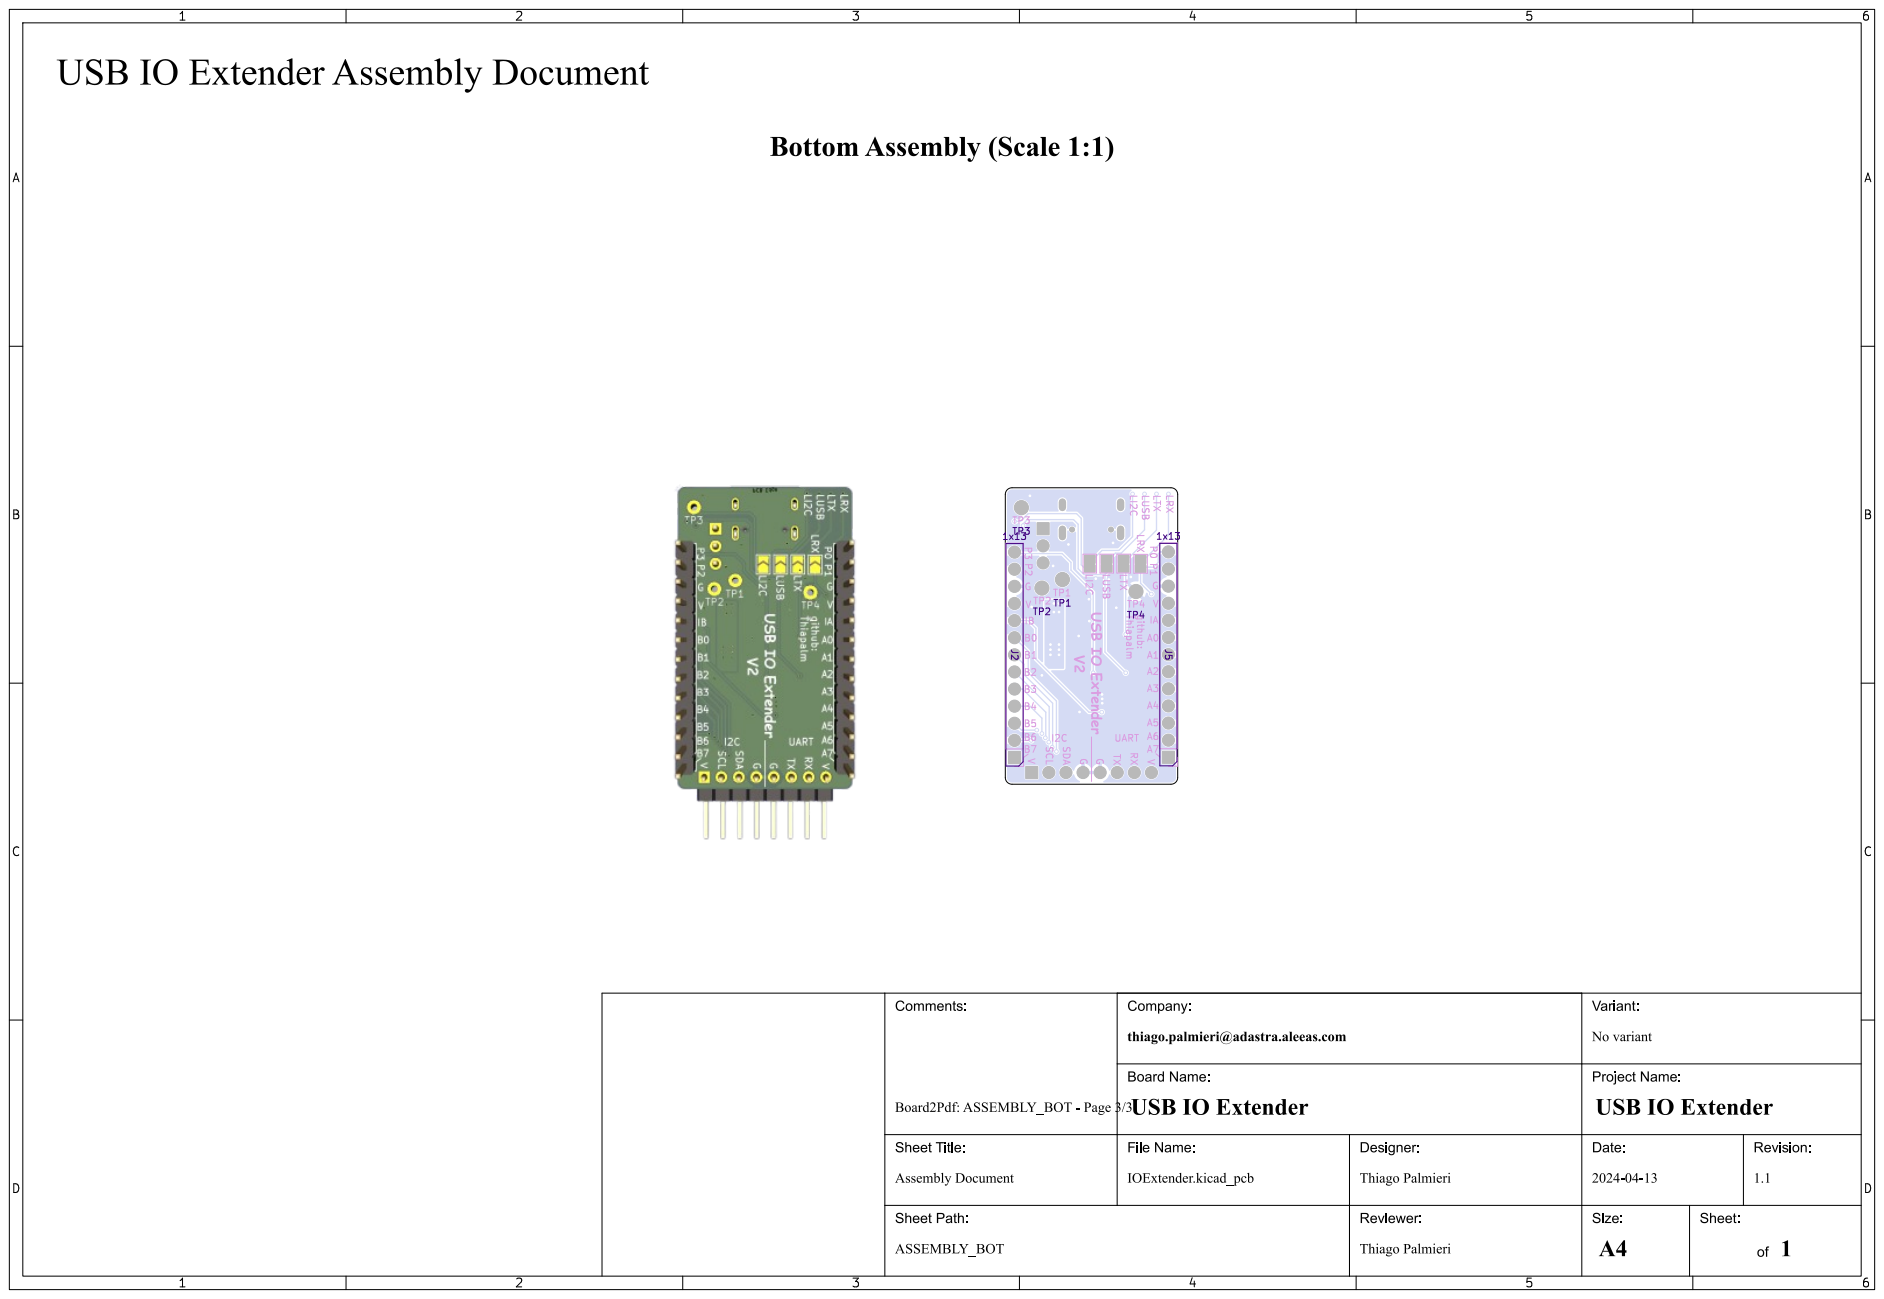
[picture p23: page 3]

thiago.palmieri@adastra.aleeas.com

Revision: 1.1 Date: Project Name: 2024-04-13 Reviewer: ThiagoPalmieri Designer:

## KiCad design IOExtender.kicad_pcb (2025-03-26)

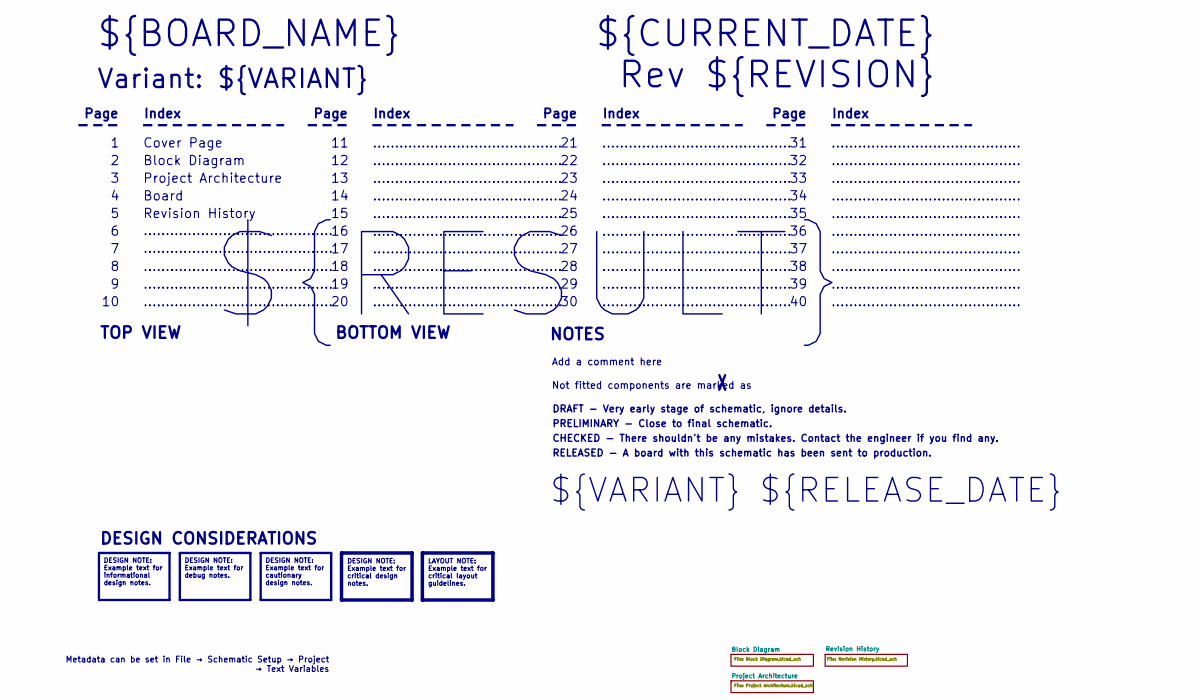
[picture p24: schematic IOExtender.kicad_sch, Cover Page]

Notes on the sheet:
BOTTOM VIEW
...........................................
RELEASED - A board with this schematic has been sent to production.
Page
TOP VIEW
Not fitted components are marked as
Index
PRELIMINARY - Close to final schematic.
${VARIANT} ${RELEASE_DATE}
Board
${RESULT}
${CURRENT_DATE}
Variant: ${VARIANT}
Rev ${REVISION}
${BOARD_NAME}
DRAFT - Very early stage of schematic, ignore details.
Block Diagram
Add a comment here
Cover Page
NOTES
Project Architecture
CHECKED - There shouldn't be any mistakes. Contact the engineer if you find any.
DESIGN CONSIDERATIONS
Revision History
Metadata can be set in File → Schematic Setup → Project → Text Variables
DESIGN NOTE: Example text for informational design notes.
LAYOUT NOTE: Example text for critical layout guidelines.
DESIGN NOTE: Example text for cautionary design notes.
DESIGN NOTE: Example text for debug notes.
DESIGN NOTE: Example text for critical design notes.

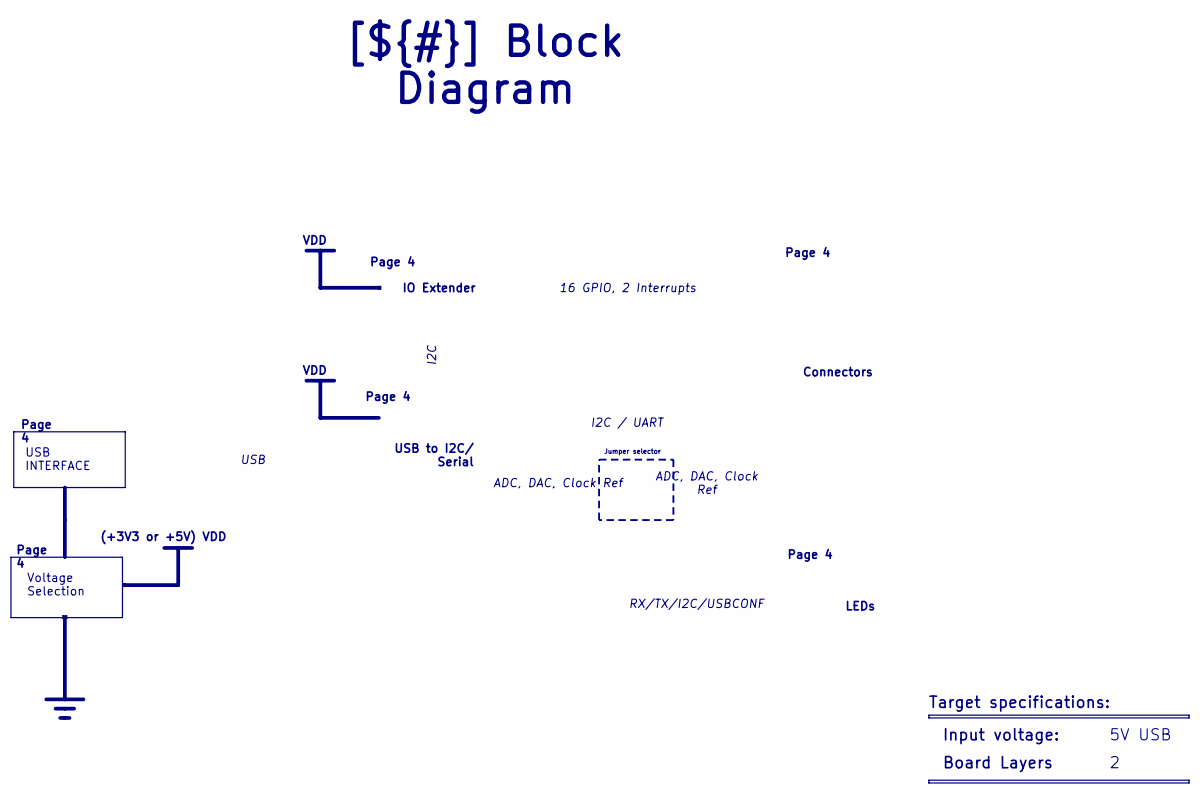
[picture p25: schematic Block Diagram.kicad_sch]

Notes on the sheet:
(+3V3 or +5V) VDD
VDD
Jumper selector
USB INTERFACE
Connectors
Board Layers
ADC, DAC, Clock Ref
Page 4
Input voltage:
USB
USB to I2C/ Serial
16 GPIO, 2 Interrupts
IO Extender
[${#}] ${TITLE}
Target specifications:
5V USB
I2C
RX/TX/I2C/USBCONF
I2C / UART
LEDs
Voltage Selection

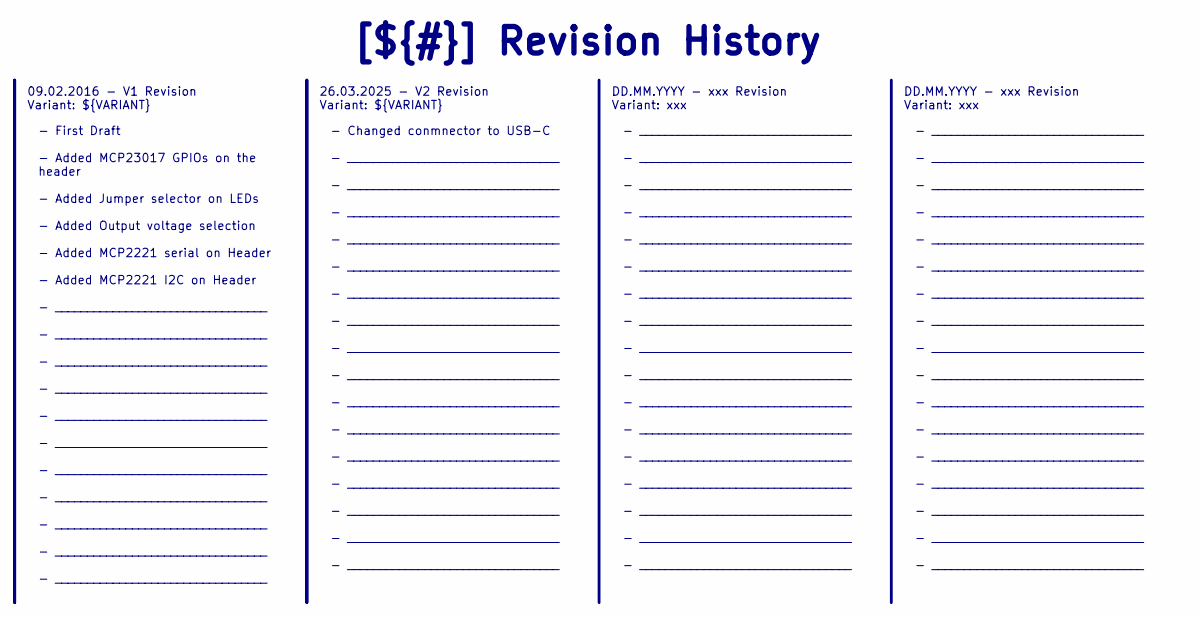
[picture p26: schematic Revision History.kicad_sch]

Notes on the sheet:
- _________________________________ - _________________________________ - _________________________________ - _________________________________ - _________________________________ - _________________________________ - _________________________________ - _________________________________ - _________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
26.03.2025 - V2 Revision Variant: ${VARIANT}
[${#}] ${TITLE}
DD.MM.YYYY - xxx Revision Variant: xxx
- First Draft - Added MCP23017 GPIOs on the header - Added Jumper selector on LEDs - Added Output voltage selection - Added MCP2221 serial on Header - Added MCP2221 I2C on Header - _________________________________ - _________________________________ - _________________________________ - __________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
09.02.2016 - V1 Revision Variant: ${VARIANT}
- Changed conmnector to USB-C - _________________________________ - _________________________________ - _________________________________ - _________________________________ - _________________________________ - _________________________________ - _________________________________ - _______________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

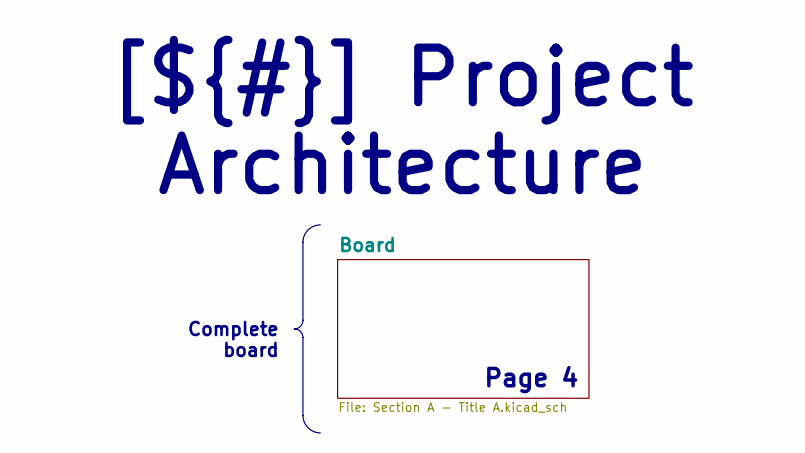
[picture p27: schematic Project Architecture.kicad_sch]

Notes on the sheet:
Page 4
Complete board
[${#}] ${TITLE}

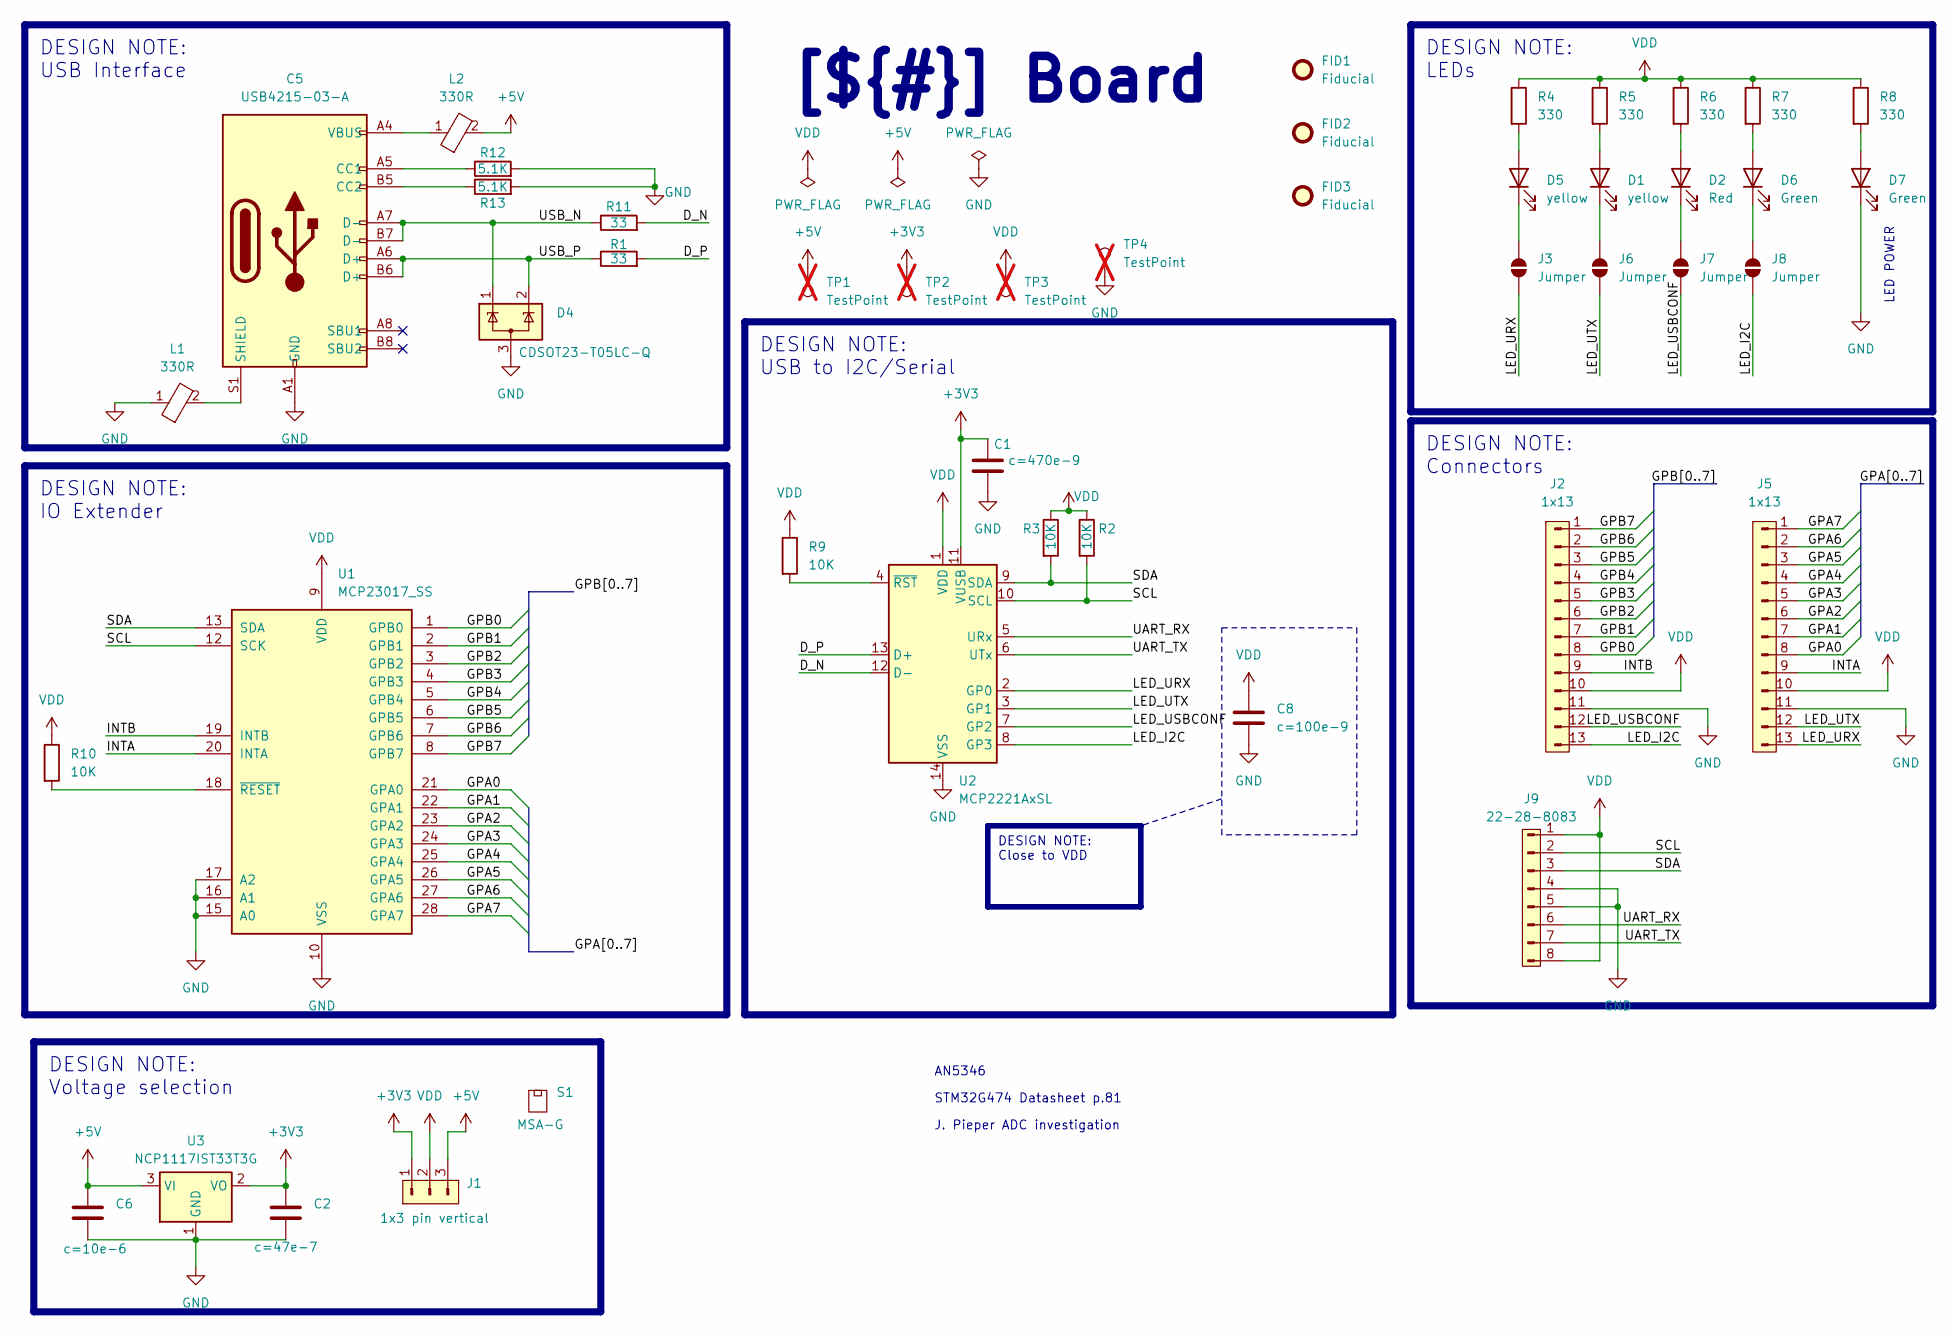
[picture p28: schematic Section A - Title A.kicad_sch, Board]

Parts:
C1: c=470e-9; C_0603_1608Metric_Pad1.08x0.95mm_HandSolder; Manufacturer Part Number C0603C474K3RACTU
C2: c=47e-7; C_0603_1608Metric_Pad1.08x0.95mm_HandSolder; Manufacturer Part Number GRM188R61E475KE11D
C5: USB4215-03-A; USB_C_Receptacle_GCT_USB4105-xx-A_16P_TopMnt_Horizontal; Manufacturer Part Number USB4215-03-A
C6: c=10e-6; C_0603_1608Metric_Pad1.08x0.95mm_HandSolder; Manufacturer Part Number C1608X5R1C106M080AB
C8: c=100e-9; C_0805_2012Metric_Pad1.18x1.45mm_HandSolder; Manufacturer Part Number 0805B104K500CT
D1, D5: yellow; LED_0603_1608Metric; Manufacturer Part Number LTST-C191KSKT
D2: Red; LED_0603_1608Metric; Manufacturer Part Number SM0603SRC
D4: CDSOT23-T05LC-Q; SOT-23-3; Manufacturer Part Number CDSOT23-T05LC-Q
D6, D7: Green; LED_0603_1608Metric; Manufacturer Part Number SML-LX0603GW-TR
FID1, FID2, FID3: Fiducial; Fiducial_0.5mm_Mask1.5mm
J1: 1x3 pin vertical; PinHeader_1x03_P2.54mm_Vertical; Manufacturer Part Number G800LR305018EU
J2, J5: 1x13; PinHeader_1x13_P2.54mm_Vertical; Manufacturer Part Number 61301311121
J3, J6, J7, J8: Jumper; SolderJumper-2_P1.3mm_Open_TrianglePad1.0x1.5mm
J9: 22-28-8083; PinHeader_1x08_P2.54mm_Horizontal; Manufacturer Part Number 22-28-8083
L1, L2: 330R; R_0805_2012Metric_Pad1.20x1.40mm_HandSolder; Manufacturer Part Number MPZ2012S331AT000
R1, R11: 33; R_0603_1608Metric_Pad0.98x0.95mm_HandSolder; Manufacturer Part Number CRCW060333R0FKEA
R2, R3, R9, R10: 10K; R_0603_1608Metric_Pad0.98x0.95mm_HandSolder; Manufacturer Part Number CRCW060333R0FKEA
R4, R5, R6, R7, R8: 330; R_0603_1608Metric_Pad0.98x0.95mm_HandSolder; Manufacturer Part Number ERJ-3GEYJ331V
R12, R13: 5.1K; R_0603_1608Metric_Pad0.98x0.95mm_HandSolder; Manufacturer Part Number CRCW06035K10FKEC
S1: MSA-G; Manufacturer Part Number MSA-G
TP1, TP2, TP3, TP4: TestPoint; TestPoint_PTH_1mm_2mm; not fitted
U1: MCP23017_SS; SSOP-28_5.3x10.2mm_P0.65mm; Manufacturer Part Number MCP23017_SS
U2: MCP2221AxSL; SOIC-14_3.9x8.7mm_P1.27mm; Manufacturer Part Number MCP2221AxSL
U3: NCP1117IST33T3G; SOT-223-3_TabPin2; Manufacturer Part Number NCP1117IST33T3G

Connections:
+3V3: C1.2, C2.2, J1.1, TP2.1, U2.11 (VUSB), U3.2 (VO)
+5V: C6.2, J1.3, L2.2, TP1.1, U3.3 (VI)
/Project Architecture/Board/D_N: R11.2, U2.12 (D-)
/Project Architecture/Board/D_P: R1.2, U2.13 (D+)
/Project Architecture/Board/GPA0: J5.8, U1.21 (GPA0)
/Project Architecture/Board/GPA1: J5.7, U1.22 (GPA1)
/Project Architecture/Board/GPA2: J5.6, U1.23 (GPA2)
/Project Architecture/Board/GPA3: J5.5, U1.24 (GPA3)
/Project Architecture/Board/GPA4: J5.4, U1.25 (GPA4)
/Project Architecture/Board/GPA5: J5.3, U1.26 (GPA5)
/Project Architecture/Board/GPA6: J5.2, U1.27 (GPA6)
/Project Architecture/Board/GPA7: J5.1, U1.28 (GPA7)
/Project Architecture/Board/GPB0: J2.8, U1.1 (GPB0)
/Project Architecture/Board/GPB1: J2.7, U1.2 (GPB1)
/Project Architecture/Board/GPB2: J2.6, U1.3 (GPB2)
/Project Architecture/Board/GPB3: J2.5, U1.4 (GPB3)
/Project Architecture/Board/GPB4: J2.4, U1.5 (GPB4)
/Project Architecture/Board/GPB5: J2.3, U1.6 (GPB5)
/Project Architecture/Board/GPB6: J2.2, U1.7 (GPB6)
/Project Architecture/Board/GPB7: J2.1, U1.8 (GPB7)
/Project Architecture/Board/INTA: J5.9, U1.20 (INTA)
/Project Architecture/Board/INTB: J2.9, U1.19 (INTB)
/Project Architecture/Board/LED_I2C: J2.13, J8.1 (A), U2.8 (GP3)
/Project Architecture/Board/LED_URX: J3.1 (A), J5.13, U2.2 (GP0)
/Project Architecture/Board/LED_USBCONF: J2.12, J7.1 (A), U2.7 (GP2)
/Project Architecture/Board/LED_UTX: J5.12, J6.1 (A), U2.3 (GP1)
/Project Architecture/Board/SCL: J9.2, R2.2, U1.12 (SCK), U2.10 (SCL)
/Project Architecture/Board/SDA: J9.3, R3.2, U1.13 (SDA), U2.9 (SDA)
/Project Architecture/Board/UART_RX: J9.6, U2.5 (URx)
/Project Architecture/Board/UART_TX: J9.7, U2.6 (UTx)
/Project Architecture/Board/USB_N: C5.A7 (D-), C5.B7 (D-), D4.1 (K), R11.1
/Project Architecture/Board/USB_P: C5.A6 (D+), C5.B6 (D+), D4.2 (K), R1.1
GND: C1.1, C2.1, C5.A1 (GND), C5.A12 (GND), C5.B1 (GND), C5.B12 (GND), C6.1, C8.1, D4.3 (A), D7.1 (K), J2.11, J5.11, J9.4, J9.5, L1.1, R12.2, R13.2, TP4.1, U1.10 (VSS), U1.15 (A0), U1.16 (A1), U1.17 (A2), U2.14 (VSS), U3.1 (GND)
unnamed: C5.A5 (CC1), R12.1
unnamed: C5.B5 (CC2), R13.1
unnamed: C5.S1 (SHIELD), L1.2
unnamed: C5.A4 (VBUS), C5.A9 (VBUS), C5.B4 (VBUS), C5.B9 (VBUS), L2.1
unnamed: D1.2 (A), R5.2
unnamed: D1.1 (K), J6.2 (B)
unnamed: D2.2 (A), R6.2
unnamed: D2.1 (K), J7.2 (B)
unnamed: D5.2 (A), R4.2
unnamed: D5.1 (K), J3.2 (B)
unnamed: D6.2 (A), R7.2
unnamed: D6.1 (K), J8.2 (B)
unnamed: D7.2 (A), R8.2
unnamed: R10.2, U1.18 (~RESET)
unnamed: R9.2, U2.4 (~RST)
VDD: C8.2, J1.2, J2.10, J5.10, J9.1, J9.8, R2.1, R3.1, R4.1, R5.1, R6.1, R7.1, R8.1, R9.1, R10.1, TP3.1, U1.9 (VDD), U2.1 (VDD)

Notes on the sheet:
LED POWER
J. Pieper ADC investigation
STM32G474 Datasheet p.81
AN5346
DESIGN NOTE: USB to I2C/Serial
DESIGN NOTE: Voltage selection
DESIGN NOTE: USB Interface
DESIGN NOTE: LEDs
[${#}] ${TITLE}
DESIGN NOTE: Close to VDD
DESIGN NOTE: Connectors
DESIGN NOTE: IO Extender

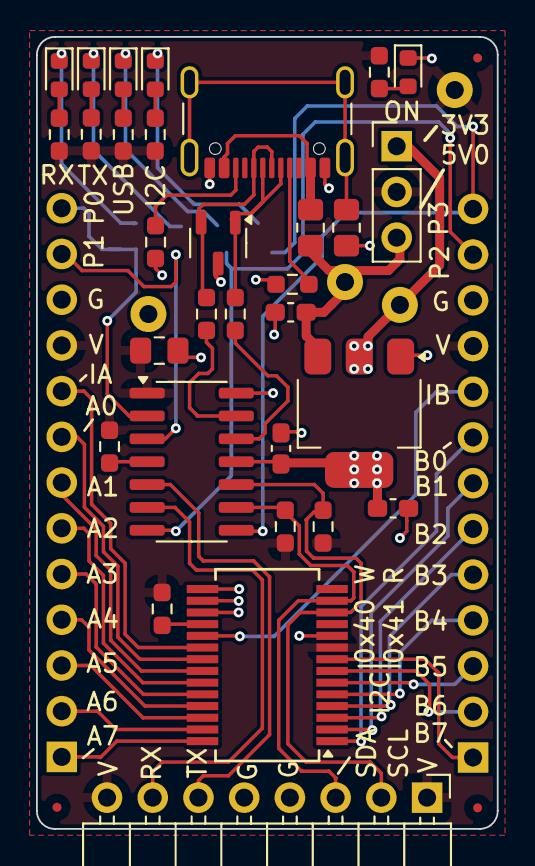
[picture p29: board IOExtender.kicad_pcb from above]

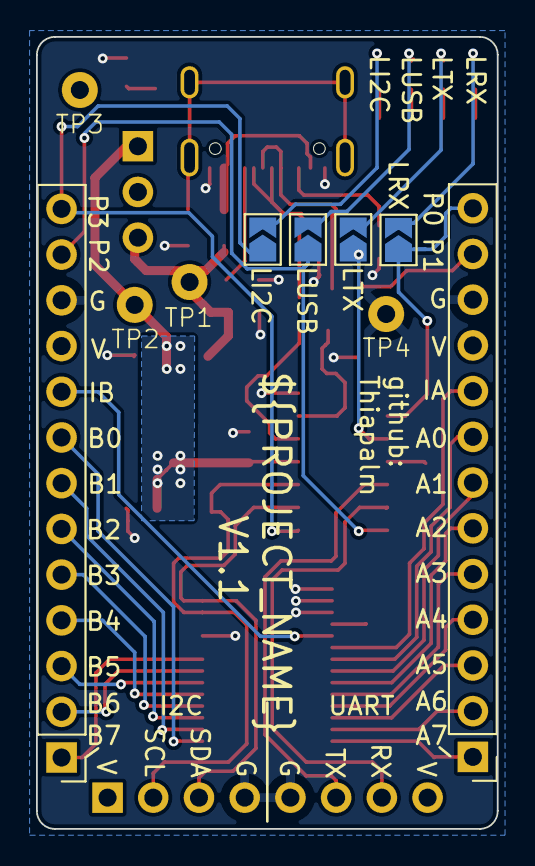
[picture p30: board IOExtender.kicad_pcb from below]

Board: 2 copper layers, 25.6 x 44.0 mm, 44 parts (10 on the bottom side), 49 nets.

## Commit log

2025-03-26 Finished board design, outputs generated
    [Block Diagram.kicad_sch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]
2025-03-26 Removed unnecessary files
    [Section B - TItle B.kicad_sch]
2025-03-26 Updated Fabrication Files
    [IOExtender-B_Mask.gbr, IOExtender-B_Paste.gbr, IOExtender-B_Silkscreen.gbr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]
2025-03-26 Removed power sequencing file
    [Power - Sequencing.kicad_sch]

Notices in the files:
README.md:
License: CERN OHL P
